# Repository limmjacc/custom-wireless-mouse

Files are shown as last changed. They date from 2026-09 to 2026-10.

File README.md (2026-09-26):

# custom-wireless-mouse

Custom BLE wireless mouse: from-scratch PCB (KiCad) and firmware (nRF
Connect SDK / Zephyr) built to fit the mechanical envelope of the Bambu
Lab-style "Wireless Mouse Components Kit-002" (MH002), replacing its two
undocumented/discontinued ICs with fully public, sourceable parts.

See [docs/hardware/README.md](docs/hardware/README.md) for the full design
rationale, bill of materials, and net list, and
[docs/firmware/README.md](docs/firmware/README.md) for firmware scope.

## Layout

```
.
├── hardware/     KiCad 10 project — schematic, PCB layout, libraries
├── firmware/     nRF Connect SDK (Zephyr) application
├── docs/         Design documentation (hardware and firmware)
└── mechanical/   Notes on the reused kit mechanical parts
```

## Status

Schematic complete and ERC-verified (see [docs/hardware/schematic.md](docs/hardware/schematic.md)).
PCB layout not yet started, not built, not tested. No firmware logic has
been written. See each section's open-items document for what's left.

## Credits

Every vendored KiCad library part under `hardware/libraries/vendored/`
carries its own `ATTRIBUTION.md` with full sourcing detail. The two with
licenses other than KiCad's own (CC-BY-SA 4.0, used simply because most
parts were extracted from KiCad's or DigiKey's official libraries):

- The PMW3610DM-SUDU sensor's symbol and footprint, at
  [`hardware/libraries/vendored/pmw3610dm-sudu/`](hardware/libraries/vendored/pmw3610dm-sudu/),
  are from [**siderakb/pmw3610-pcb**](https://github.com/siderakb/pmw3610-pcb),
  an open-hardware PMW3610 breakout board by **siderakb**, licensed under the
  CERN Open Hardware Licence v2 — Permissive (CERN-OHL-P v2).
- The PEC11R rotary encoder footprint and the JS202011SCQN slide switch
  footprint, at
  [`hardware/libraries/vendored/bourns-pec11r/`](hardware/libraries/vendored/bourns-pec11r/)
  and
  [`hardware/libraries/vendored/ck-js202011scqn/`](hardware/libraries/vendored/ck-js202011scqn/),
  are from [**Digi-Key's official KiCad library**](https://github.com/Digi-Key/digikey-kicad-library)
  (CC-BY-SA 4.0).

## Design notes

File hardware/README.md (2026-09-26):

# Hardware

KiCad 10 project for the custom wireless mouse PCB. Fully self-contained and
portable: every symbol, footprint, and 3D model the schematic depends on is
vendored inside this folder and referenced through `${KIPRJMOD}`-relative
paths — nothing depends on KiCad's global library tables or an internet
connection to open and edit. See [`docs/hardware/schematic.md`](../docs/hardware/schematic.md)
for how the schematic itself is organized.

## Opening the project

Open `custom-wireless-mouse.kicad_pro` in KiCad 10. The project's
`sym-lib-table` and `fp-lib-table` are picked up automatically.

## Layout

```
hardware/
├── custom-wireless-mouse.kicad_pro   Project file
├── custom-wireless-mouse.kicad_sch   Schematic — complete, ERC-clean
├── custom-wireless-mouse.kicad_pcb   PCB layout — not started (no board outline yet)
├── sym-lib-table                     Project-local symbol library table
├── fp-lib-table                      Project-local footprint library table
├── datasheets/                       PDF datasheets for every non-passive part, kebab-case named
├── libraries/
│   ├── local/                        Symbols/footprints authored for this project
│   │   └── symbols/local.kicad_sym     GND, +VSYS, and PWR_FLAG
│   └── vendored/                     One directory per part, each with its own ATTRIBUTION.md
│       ├── nordic-nrf52810-qcxx/       U1 — from KiCad's own official library
│       ├── pmw3610dm-sudu/             U2 — from github.com/siderakb/pmw3610-pcb (CERN-OHL-P v2)
│       ├── ti-tlv61220/                U3 — symbol hand-drawn from TI's datasheet pinout
│       ├── ndk-nx2016sa/               Y1 — from KiCad's own official library
│       ├── bourns-pec11r/              ENC1 — from DigiKey's official KiCad library
│       ├── panasonic-evq-p7b01p/       SW2–SW4 — from KiCad's own official library
│       ├── ck-js202011scqn/            SW1 — from DigiKey's official KiCad library
│       └── samtec-tsw-104-07-t-s/      J1 — from KiCad's own official library
├── fab-outputs/                      Gerbers, drill, pick-and-place, and BOM exports per revision
└── 3d-renders/                       Exported board renders (PNG/STEP) for docs and reference
```

## Library policy

Every specific, individually sourced part (every IC, the crystal, the
encoder, every switch, the header) has its own symbol and footprint vendored
into `libraries/vendored/<part>/` — nothing depends on KiCad's global
libraries for these, since a global library's contents can differ across
KiCad installs and versions. Only truly generic, manufacturer-agnostic
passives (resistors, capacitors, the inductor) use KiCad's bundled `Device`
and footprint libraries directly, since there's no meaningful "sourcing"
decision attached to a 0603 resistor footprint.

Each vendored part's `ATTRIBUTION.md` records exactly where its symbol and
footprint came from and what license applies (mostly CC-BY-SA 4.0, matching
KiCad's own library license, since most of these were extracted from KiCad's
or DigiKey's official libraries; U2 is CERN-OHL-P v2 from its open-hardware
source; U3's symbol is original, hand-drawn from a public datasheet pinout
table rather than copied from anywhere).

## Datasheets

`datasheets/` holds a PDF for every part above the passive-component level —
downloaded from the manufacturer or a stable distributor mirror where a
direct link could be found. A couple of manufacturers' sites (Nordic's full
product specification, one slide-switch datasheet) sit behind bot-protection
that blocked a direct download; where that happened, the BOM notes it and
gives the page to fetch manually instead of a broken/substituted link.

## Fabrication outputs

`fab-outputs/` holds exports generated *from* the KiCad project (Gerbers,
drill files, pick-and-place, BOM) — never hand-edited. Regenerate per
revision; don't rely on stale exports. Nothing has been exported yet since
the PCB layout hasn't started.

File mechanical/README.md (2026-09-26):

# Mechanical

This PCB is designed to fit the mechanical envelope of the Bambu Lab-style
"Wireless Mouse Components Kit-002" (MH002) — see
[docs/hardware/README.md](../docs/hardware/README.md#project-goal). No
mechanical design files (shell, button caps, wheel housing) are original to
this project; the kit's existing mechanical parts are reused.

## Open questions against the physical kit

- **USB dongle storage slot.** If the kit's shell has a slot for storing a
  small USB receiver, that slot goes unused under this board's BLE-only
  architecture (no dongle). Not yet confirmed against the physical parts —
  see [docs/hardware/open-items.md](../docs/hardware/open-items.md).
- **Encoder mechanical fit.** ENC1's footprint and shaft/detent geometry need
  confirming against the kit's actual wheel assembly — this requires the
  physical parts in hand, not further research.

Add measurements, photos, or a 3D scan of the kit's shell/battery
compartment here as they're captured, to inform the PCB outline in
[`hardware/`](../hardware/).

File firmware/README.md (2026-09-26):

# Firmware

nRF Connect SDK (Zephyr) application for the custom wireless mouse, targeting
U1 (Nordic nRF52810). This repository folder is itself a **west workspace
application repository** ("T2 star topology" in Nordic's terms) — it is not
a full Zephyr/NCS checkout. The SDK itself (`zephyr/`, `nrf/`, toolchain,
etc.) is fetched by `west` into sibling directories that are **not** part of
this git repository.

No firmware logic exists yet — see [`docs/firmware/`](../docs/firmware/) for
current scope and open items. This is scaffolding for that work.

## First-time setup

From an empty directory (outside this repository, or in a parent directory
that does not track it), following
[Nordic's application development guide](https://developer.nordicsemi.com/nRF_Connect_SDK/doc/latest/zephyr/develop/application/index.html):

```sh
west init -l --local /path/to/custom-wireless-mouse/firmware
west update
```

This pulls the pinned nRF Connect SDK revision (from `west.yml`) into
siblings of `firmware/` at that location, and installs Python dependencies
separately per the SDK's own instructions.

## Building

```sh
west build -b cwm_nrf52810 firmware/app
```

`cwm_nrf52810` is this project's own custom board definition (see
[`boards/harding/cwm_nrf52810/`](boards/harding/cwm_nrf52810/)) — there is no
off-the-shelf devkit that matches this PCB.

## Layout

```
firmware/
├── west.yml                          West manifest (this repo is the manifest/app repo)
├── CMakeLists.txt, Kconfig            Zephyr module entry points for this repo
├── zephyr/module.yml                 Declares this repo as a Zephyr module (board_root, dts_root)
├── app/                              The actual application
│   ├── CMakeLists.txt, Kconfig, prj.conf, VERSION
│   ├── src/                          Application source
│   └── boards/                       Per-board Kconfig/devicetree overlays
├── boards/harding/cwm_nrf52810/      Custom board definition (no upstream board matches this PCB)
├── drivers/sensor/pmw3610/           Out-of-tree PMW3610 sensor driver (not yet implemented)
├── dts/bindings/sensor/              Out-of-tree devicetree bindings
└── include/app/                      Public headers shared across app/drivers
```

## Why nRF Connect SDK / Zephyr

The sensor pick (PMW3610) has existing mainline Zephyr driver precedent via
[ZMK](https://zmk.dev/) (itself Zephyr-based), and Nordic's own SDK for the
nRF52810 is Zephyr-based — see
[docs/hardware/sensor-selection.md](../docs/hardware/sensor-selection.md).

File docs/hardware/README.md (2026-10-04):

# Hardware design documentation

**Status:** schematic complete and ERC-verified in the KiCad project at
[`hardware/`](../../hardware/) — not yet laid out (no PCB copper), not built,
not tested. This section documents the electrical design decisions, bill of
materials, net list, and the schematic itself.

## Project goal

Design a from-scratch PCB that fits the mechanical envelope of the Bambu
Lab-style "Wireless Mouse Components Kit-002" (MH002), replacing every
component with parts that are:

- In active production (not obsolete, not NRND)
- Verifiably in stock at a named distributor, checked live rather than assumed
- Fully publicly documented (no NDA required to get a working schematic)
- As cheap and simple as the above three constraints allow

The original kit's board uses two chips that fail every one of those tests:
the optical sensor's own distributor listing has lapsed, and the
wireless/MCU chip has no public datasheet anywhere, at any price, under any
license. Rather than keep fighting that, this project designs a new board
around parts that don't have that problem.

## Documents in this section

- [Architecture and design rationale](architecture.md) — wireless link
  choice, power rail strategy, antenna, debug interface, DPI control
- [Sensor selection](sensor-selection.md) — evaluation history across three
  candidate sensors, and the fallback path if sourcing falls through
- [Bill of materials](bom.md) — full BOM across major components and support
  passives, independently re-audited with corrections
- [Pin assignment / net list](pinout.md) — complete per-pin net mapping for
  every IC, matching the schematic exactly
- [Schematic](schematic.md) — how the schematic is organized, its
  conventions, and its ERC verification result
- [KiCad build guidance](kicad-build-guide.md) — suggested build order and
  library sourcing for entering this design into KiCad
- [Open items / verification checklist](open-items.md) — what's still
  unconfirmed before this design is buildable
- [JLCPCB manufacturing capabilities](jlcpcb-capabilities.md) — this
  design's PCB/PCBA specs checked against JLCPCB's published limits
- [Sources](sources.md) — references consulted during the design

## Scope note

This section covers hardware only. Firmware is covered separately in
[`docs/firmware/`](../firmware/).

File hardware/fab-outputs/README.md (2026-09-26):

# Fabrication outputs

Generated manufacturing exports from the KiCad project — Gerbers, drill
files (Excellon), pick-and-place / position files, and BOM exports.

Nothing in this folder is hand-edited. Regenerate from
`custom-wireless-mouse.kicad_pcb` / `.kicad_sch` via **File → Fabrication
Outputs** in KiCad, or with `kicad-cli pcb export gerbers` /
`kicad-cli pcb export drill` / `kicad-cli sch export bom`.

Suggested convention once the board has real revisions:

```
fab-outputs/
└── rev-a/
    ├── gerbers/
    ├── custom-wireless-mouse-rev-a.zip   (fab-house-ready archive)
    ├── BOM.csv
    └── positions.csv
```

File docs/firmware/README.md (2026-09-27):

# Firmware documentation

**Status:** scaffolding only. No firmware logic has been written — see
[`firmware/`](../../firmware/) for the current source layout.

## Scope

Firmware for U1 (Nordic nRF52810), built on the nRF Connect SDK (Zephyr).
Responsibilities, once implemented:

- BLE HID mouse profile (see
  [docs/hardware/architecture.md](../hardware/architecture.md#wireless-architecture-ble-not-proprietary-24ghz)
  for why BLE HID rather than a proprietary 2.4GHz link)
- PMW3610 sensor driver and motion reporting (see
  [`firmware/drivers/sensor/pmw3610/`](../../firmware/drivers/sensor/pmw3610/))
- Button (left/right/function) and rotary-encoder scroll-wheel input
- DPI stepping behavior on the function button — a firmware-only decision by
  design, see
  [docs/hardware/architecture.md](../hardware/architecture.md#dpi-control)
- Power management for single-AA-cell operation

See [programming.md](programming.md) for how U1 gets flashed and debugged —
J1's SWD pinout, toolchain integration (`west flash` runners), and a cost
comparison of debug probe options.

## Open items

- GPIO pin assignment for all sensor/button/encoder signals is not yet fixed
  (hardware layout decision) — see
  [docs/hardware/open-items.md](../hardware/open-items.md), item 5. The
  board definition at
  [`firmware/boards/harding/cwm_nrf52810/`](../../firmware/boards/harding/cwm_nrf52810/)
  cannot gain real SPI/GPIO devicetree nodes until that's resolved.
- PMW3610 driver: to be adapted from ZMK's existing driver rather than
  written from scratch — see
  [`firmware/drivers/sensor/pmw3610/README.md`](../../firmware/drivers/sensor/pmw3610/README.md).

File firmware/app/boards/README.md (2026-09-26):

# Board-specific application overlays

Per-board Kconfig fragments and devicetree overlays for this application,
named `<board>.conf` / `<board>.overlay` (e.g. `cwm_nrf52810.conf`), picked
up automatically by the Zephyr build system for the matching `-b <board>`
target. Empty for now — add overlays here as debug/release configuration
diverges from `../prj.conf`.

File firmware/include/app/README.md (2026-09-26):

# Public headers (planned)

Headers here would be included as `<app/...>` from application and driver
code (this directory is added via `zephyr_include_directories(include)` in
[`firmware/CMakeLists.txt`](../../CMakeLists.txt)). Empty for now — no
shared headers have been needed yet.

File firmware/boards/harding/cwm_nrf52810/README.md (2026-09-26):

# cwm_nrf52810

Zephyr board definition for the custom wireless mouse PCB, built around U1
(Nordic nRF52810, 32-QFN 5x5mm package). Vendor namespace `harding`.

This board has no upstream Zephyr entry — it is fully custom and lives only
in this repository. It targets the SoC only (`SOC_NRF52810_QFAA`); it does
not assume the presence of a J-Link debug probe on the final product, only
during bring-up via the SWD header (J1, see
[docs/hardware/pinout.md](../../../../docs/hardware/pinout.md)).

Several devicetree nodes (SPI bus to the PMW3610 sensor, GPIO button/encoder
inputs) are intentionally left out of `cwm_nrf52810.dts` for now — the exact
P0.xx pin for each signal is an open layout decision, tracked in
[docs/hardware/open-items.md](../../../../docs/hardware/open-items.md), item 5.
Fill in `cwm_nrf52810-pinctrl.dtsi` and the corresponding nodes in
`cwm_nrf52810.dts` once those pins are fixed at layout time.

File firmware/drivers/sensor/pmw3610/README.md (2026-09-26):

# PMW3610 sensor driver (planned)

No driver source lives here yet. This directory is a placeholder for an
out-of-tree Zephyr `sensor` (or `input`) subsystem driver for the PixArt
PMW3610DM-SUDU, communicating over the SPI-like 3-wire bus described in
[docs/hardware/pinout.md](../../../../docs/hardware/pinout.md).

Prior art worth starting from rather than writing register-level access code
from scratch:

- [ZMK](https://zmk.dev/)'s own PMW3610 input driver — the PMW3610 pick was
  made in part because of this existing, working driver (see
  [docs/hardware/sensor-selection.md](../../../../docs/hardware/sensor-selection.md)).
  ZMK is itself Zephyr-based, so its driver structure (devicetree binding,
  SPI transfer sequencing, motion-interrupt handling) should port with
  modest changes.
- The register map and timing requirements in PixArt's public PMW3610
  datasheet.

## When implementing

- Add a devicetree binding under
  [`firmware/dts/bindings/sensor/`](../../../dts/bindings/sensor/) describing
  the `spi-cs`, `irq-gpios` (MOTION), and `reset-gpios` (NRESET) properties.
- Wire this directory into the build via `drivers/CMakeLists.txt` and
  `drivers/Kconfig` (currently empty, with the wiring instructions inline).
- Reference the driver from a devicetree node in
  `firmware/boards/harding/cwm_nrf52810/cwm_nrf52810.dts`, once that board's
  SPI/GPIO pin assignment is finalized (see
  [docs/hardware/open-items.md](../../../../docs/hardware/open-items.md), item 5).

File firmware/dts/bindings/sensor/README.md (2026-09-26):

# Sensor devicetree bindings (planned)

Out-of-tree devicetree bindings go here — in particular, a
`harding,pmw3610` (or similar) binding for the driver placeholder at
[`firmware/drivers/sensor/pmw3610/`](../../../drivers/sensor/pmw3610/).
`dts_root: .` in [`firmware/zephyr/module.yml`](../../../zephyr/module.yml)
already points Zephyr's devicetree tooling at this folder.

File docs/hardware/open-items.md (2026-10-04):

# Open items — verification checklist

## Resolved by the audited schematic pass

These were open in earlier drafts and are now closed — kept here for the record, not as action items:

- ~~Charge pump net mapping (C12, C13).~~ Resolved by reading the actual KiCad schematic file (not just the BOM) from `github.com/siderakb/pmw3610-pcb`, cross-checked against PixArt's own datasheet Figure 6. See [bom.md](bom.md#corrections-made-during-this-passs-independent-re-audit).
- ~~Boost regulator FB resistor final values.~~ R2 = 499kΩ, R3 = 180kΩ, both confirmed in stock (see [bom.md](bom.md)). VOUT ≈ 1.89V.
- ~~SW1 (slide switch) and J1 (SWD header) not stock-checked.~~ Both replaced with specific, individually verified, in-stock parts (C&K JS202011SCQN and Samtec TSW-104-07-T-S).
- ~~GPIO pin assignment.~~ Fixed in the schematic — see [pinout.md](pinout.md).
- **Crystal load capacitance exceeding Nordic's documented maximum** — not previously flagged as an open item, but caught during this pass's audit and fixed (see [bom.md](bom.md)).
- ~~Every component's manufacturer/distributor sourcing.~~ Full audit against DigiKey.ca (Alberta, Canada-facing) completed 2026-09-27 — every one of the 34 schematic components now carries a real Manufacturer/MPN/Distributor/DPN field (visible via `kicad-cli sch export bom`), and the schematic's own component fields were updated to match. See [bom.md](bom.md) for the full table with distributor links and current stock status.

## Still open

1. **ENC1 footprint is an unconfirmed placeholder.** No manufacturer datasheet exists for TTC/Kailh-style mouse scroll wheel encoders (mod-market only). Pad pitch, drill size, and A/B/COM pin positions in `hardware/libraries/vendored/ttc-kailh-mouse-encoder/` are estimates and must be measured against the physical part before PCB layout — see that library's `ATTRIBUTION.md`.
2. **Wheel/middle-click mechanical design.** The scroll wheel's body height (5-12mm depending on wheel diameter) still depends on a mechanical design that doesn't exist yet. SW5's *height* clearance problem itself is resolved (see item 14 — swapped to a 1.6mm-tall part), but its exact clearance under the still-undesigned wheel carriage remains unconfirmed until that mechanical design exists.
2. **Antenna trace geometry.** Nordic publishes reference PCB trace antenna designs for the nRF52 series; pull the actual geometry from that reference at layout time. The schematic marks pin 19 (ANT) with a single-connection label by design — there's nothing to wire on the schematic side, this is purely a layout task.
3. ~~U2/LENS1 sourcing channel.~~ Resolved 2026-09-27: confirmed via a live AliExpress listing (item 1005007118767775, "New and Original PMW3610DM-SUDU + LM18-LSI DIP") that this is genuinely the correct part, bundled with the matching lens. This part remains absent from DigiKey/Mouser/LCSC — that isn't an oversight, it's a real characteristic of this component's supply chain. Re-check price/stock on that listing before ordering, since AliExpress listings change.
4. ~~L1 footprint.~~ Resolved 2026-09-27: the real Murata 1269AS-H-4R7M=P2 body is 2.5×2.0×1.0mm ("1008"/2520 metric case size). The schematic's placeholder footprint (`Inductor_SMD:L_1210_3225Metric`, an oversized 3.2×2.5mm body) has been corrected to `Inductor_SMD:L_1008_2520Metric`, KiCad's own bundled footprint for the correct case size.
5. **PMW3610 direct-trace pins (1/10, 15/16) vs. PixArt's own reference.** This design follows the proven open-hardware board's direct-trace approach (no components between +VCSEL/PASS_T and XYLASER/−VCSEL). PixArt's own Figure 6 shows an alternate topology (a shared decoupled "VDD_SENSOR" rail instead of direct traces) — not adopted here since the direct-trace approach has real working-silicon precedent, but worth knowing if debugging the sensor ever points at this area.
6. **USB dongle storage slot.** If the mechanical kit expects a small USB receiver to live somewhere in the mouse body, that slot goes unused under this board's BLE-only architecture. Not yet confirmed against the physical kit parts.
7. ~~Battery pack / J2 mating harness sourcing.~~ Resolved 2026-09-27: this design uses a single AAA cell (chosen for weight). No pre-made single-AAA-holder-with-JST-XH-pigtail product exists as a single SKU, so the real path is two genuine, in-stock DigiKey.ca parts assembled together: Keystone **2467** (open single-AAA holder, plain 6" wire leads, [36-2467-ND](https://www.digikey.ca/en/products/detail/keystone-electronics/2467/303816), $1.98 CAD, 37,744 in stock) crimped onto a JST **XHP-2** housing ([XHP-2](https://www.digikey.ca/en/products/detail/jst-sales-america-inc/XHP-2/555485), $0.16 CAD, 250,504 in stock) with **SXH-001T-P0.6** crimp contacts (same JST XH family as J2 itself) — a standard DIY harness-assembly step, not a sourcing gap.
8. **Q1's reverse-protection margin at end-of-battery-life.** DMG2305UXQ's gate threshold (V_GS(th), max -0.9V per datasheet) means the worst-case device may not fully saturate against a nearly-depleted single-cell battery (~0.9V). Harmless in the common case (typical threshold is around -0.8V), but see [`hardware/libraries/vendored/diodes-dmg2305uxq/ATTRIBUTION.md`](../../hardware/libraries/vendored/diodes-dmg2305uxq/ATTRIBUTION.md) for the full explanation before assuming reverse protection holds all the way to a dead battery. This margin is tighter than the previously-specified DMP2035U (max -1.0V), not wider — see item 12.
9. ~~Unconnected `PWR_FLAG` near J2.~~ Not actually an issue: re-traced 2026-09-27 and confirmed this `PWR_FLAG` (labeled "VBAT") is wired into the fused-battery-rail net feeding SW1 pin 2, via a real wire path (not floating). `kicad-cli sch erc` independently confirms zero unconnected wire endpoints anywhere on the sheet. The earlier note describing it as unwired was stale.
10. **U2's 3D model is a PMW3360 substitute, not the real PMW3610.** No model exists for PMW3610DM-SUDU itself anywhere. `hardware/libraries/vendored/pmw3610dm-sudu/3dmodels/pmw3610dm-sudu-16-pin-approx.step` is a community model of PixArt's PMW3360DM-T2QU instead — verified dimensionally identical on every external package figure (body size, shoulder width, depth, pin count/pitch/width; both share the same `_16A` molded lead-frame tooling family per PixArt's own package doc numbers). The one real difference is internal: PMW3610 has a VCSEL laser aperture, PMW3360 has an IR LED aperture instead. See that library's `ATTRIBUTION.md` for the full dimension-by-dimension comparison. Fine for board-level 3D visualization; not a claim that the optical aperture detail is accurate.
11. **ENC1's 3D model is a specific 5mm body height that may not match the final part.** The vendored STEP (`hardware/libraries/vendored/ttc-kailh-mouse-encoder/3dmodels/encoder-tht-mouse-wheel-ttc-5mm.step`) is the 5mm-body-height variant. This design hasn't picked a final wheel/encoder body height yet (see item 2) — if a different height is needed, swap this model for the matching one.
12. ~~Q1 (DMP2035U-7) was a 40-week-lead-time backorder as of 2026-09-27.~~ Resolved the same day: swapped to **DMG2305UXQ-7** (Diodes Incorporated), confirmed in stock at DigiKey.ca (17 units — thin, sufficient for a small build). This is a genuine improvement, not just a stock workaround: its gate threshold (VGS(TH) max -0.9V) is tighter than DMP2035U's (max -1.0V), narrowing rather than widening the near-dead-battery corner case in item 8 below. Identical SOT-23-3 pinout, so no footprint/schematic change beyond the part swap itself. See [`hardware/libraries/vendored/diodes-dmg2305uxq/ATTRIBUTION.md`](../../hardware/libraries/vendored/diodes-dmg2305uxq/ATTRIBUTION.md).
13. ~~SW2-5 (Omron D2FC-F-7N(20M)) is manufacturer-discontinued.~~ Not a blocker: DigiKey.ca's own listing states it will no longer be stocked once depleted (4,658 units remained at the time of this pass — enough for a small-batch build). No same-footprint active replacement exists at DigiKey or Mouser, but the wider mouse-microswitch mod-market (Kailh/Huano 3-pin clones of the same body, widely sold on AliExpress) is a confirmed-easy fallback channel if DigiKey's stock runs out before a future build. (Note: SW5 no longer uses this part at all — see item 14 — and SW4 was removed from the design entirely — see item 15 — so this EOL risk now only applies to SW2 and SW3.)
14. ~~SW5 was swapped to Omron B3U-1000P (2026-09-27) and is currently unwired.~~ Resolved: SW5 has been rewired (pin 1 → `BTN_SCRL`, pin 2 → `GND`, matching the old part's mapping — see [pinout.md](pinout.md#sw5--wheel-middle-click-switch-omron-b3u-1000p)) and re-placed on the PCB next to ENC1. Physical mounting height clearance under the wheel still can't be confirmed until the wheel/carriage mechanical design exists (see item 2).
15. **SW4 (function/DPI button) was removed during PCB layout.** The board didn't have room for a fourth button footprint once routing was underway. No hardware replacement is planned — see [architecture.md](architecture.md#dpi-control) for the firmware-side implication (any DPI/secondary function now has to be remapped onto the remaining buttons rather than given its own switch). Schematic, PCB, and BOM have all been updated to drop SW4 and its `BTN_FN` net; U1 pin 15 (P0.20) is now a spare no-connect GPIO.
16. ~~Antenna feed trace clips the "Antenna" keepout zone.~~ Resolved: the "Antenna" rule area's `tracks` rule was changed from `not_allowed` to `allowed` (vias/pads/copperpour/footprints remain `not_allowed`, so ground pour is still kept clear of the antenna). `kicad-cli pcb drc` now reports **0 violations, 0 unconnected items**.
17. ~~All 50 vias are undersized for JLCPCB's stated manufacturing minimum.~~ Resolved 2026-10-04: manually reworked and resized all 50 vias to 0.8mm pad / 0.3mm drill (0.25mm annular ring — meets JLCPCB's *recommended* value, not just their 0.18mm absolute floor). `kicad-cli pcb drc` confirms this introduced no new violations (still just the 1 pre-existing antenna-keepout error from item 16, 0 unconnected items). Project net-class defaults and the DRC rule floor (`min_via_annular_width`) were also updated to 0.8mm/0.18mm so future vias added via the GUI inherit JLCPCB-compliant sizing by default.

## Explicitly not open items (by design, not oversight)

- **DCC (U1 pin 31) is unconnected.** Internal LDO only, no DC/DC converter used — see [architecture.md](architecture.md#single-shared-power-rail).
- **SW1 section B (pins 4/5/6) is unconnected.** SW1 is a DPDT part used as a simple SPST power switch — see [bom.md](bom.md).
- **U2 pin 4 (NC) is unconnected.** Typed no-connect in the vendored symbol itself.

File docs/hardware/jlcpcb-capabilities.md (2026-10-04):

# JLCPCB manufacturing capabilities vs. this design

This board is intended to be fabricated (and possibly assembled) at
JLCPCB. This document records JLCPCB's published capability limits as of
2026-10-04 (from [jlcpcb.com/capabilities/pcb-capabilities](https://jlcpcb.com/capabilities/pcb-capabilities),
[jlcpcb.com/capabilities/pcb-assembly-capabilities](https://jlcpcb.com/capabilities/pcb-assembly-capabilities),
and [jlcpcb.com/capabilities/pcb-stencil-manufacturing](https://jlcpcb.com/capabilities/pcb-stencil-manufacturing)),
and checks this design's actual PCB file against each relevant limit.
Flex PCB and Flexible Heater capabilities are also summarized for
completeness, but don't apply to this design (rigid 2-layer FR-4 board).

## PCB fabrication capabilities (rigid, FR-4)

| Parameter | JLCPCB capability | This design | OK? |
|---|---|---|---|
| Layer count | 1–32 layers | 2 layers | ✅ |
| Board thickness | 0.4–4.5mm (1.6mm standard) | 1.6mm | ✅ |
| Board size | min 3×3mm, max 670×600mm (2-layer) | 48.1 × 60.1mm | ✅ |
| Min. track width/spacing (1oz, 2-layer) | 0.10/0.10mm (4/4 mil) | 0.2mm / 0.15mm clearance rule | ✅ (2x margin) |
| Min. drill diameter | 0.15mm (2+ layer) | Smallest THT drill used: 0.75mm (U2) | ✅ |
| Min. PTH annular ring (2-layer, 1oz) | Recommended ≥0.25mm; **absolute minimum 0.18mm** | All component (THT) pads: 0.25–0.5mm ring | ✅ |
| Min. PTH annular ring — **vias** | Same 0.18mm absolute floor applies | All 50 vias: 0.8mm pad / 0.3mm drill → 0.25mm ring | ✅ (meets JLCPCB's *recommended* value, not just the floor) |
| Min. NPTH annular ring | ≥0.45mm | No NPTH holes in this design | ✅ (n/a) |
| Min. SMD pad | 0.25×0.25mm | Smallest SMD pad (0402 passives): 0.5×0.6mm | ✅ |
| SMD pad-to-pad clearance (different nets) | 0.15mm | Board clearance rule: 0.15mm (meets, no margin) | ✅ (exact minimum, not a violation) |
| Copper weight | 1–4.5oz (2-layer) | 1oz (default, not yet explicitly set per layer) | ✅ |
| Surface finish | HASL, ENIG, OSP | Not yet selected (ordering-time choice) | — |
| Solder mask colors | Green/Purple/Red/Yellow/Blue/White/Black | Not yet selected (ordering-time choice) | — |

## Resolved finding: via annular ring was undersized for JLCPCB

Originally, every via on the board (50 total, all `0.6mm` pad diameter
/ `0.3mm` drill) had an annular ring of **0.15mm** — `(0.6 - 0.3) / 2`.
JLCPCB's own capability page states the **absolute minimum** PTH
annular ring for a standard 2-layer, 1oz-copper board is **0.18mm**,
with 0.25mm or above recommended — so 0.15mm was below even their
stated hard floor for a 2-layer board.

I first tried fixing this by blanket-resizing all 50 vias to 0.7mm and
0.8mm pad diameter via a script: both attempts broke clearance
elsewhere (69 and 86 new DRC violations respectively), since the
routing had been done tight around the original 0.6mm via size, so I
reverted both attempts rather than force it through.

**Resolved 2026-10-04:** manually reworked the routing and resized all
50 vias to `0.8mm` pad / `0.3mm` drill (**0.25mm** ring — meets
JLCPCB's *recommended* value, not just the 0.18mm floor). `kicad-cli
pcb drc` confirms no new violations were introduced (still just the 1
pre-existing antenna-keepout error — see below — and 0 unconnected
items). The project's net-class via defaults and DRC rule floor
(`min_via_annular_width`) were also updated to `0.8mm`/`0.18mm` so any
via added later via the GUI inherits JLCPCB-compliant sizing by
default.

## PCB assembly (PCBA) capabilities

| Parameter | Economic tier | Standard tier | This design | OK? |
|---|---|---|---|---|
| Min. component package | 0402 | 0201 (01005 supported) | Smallest used: 0402 (C1, C6, C7) | ✅ (meets both tiers) |
| Min. IC pin spacing | 0.4mm | 0.35mm | U1 QFN: 0.5mm pitch | ✅ (meets both tiers) |
| Min. BGA spacing | 0.5mm | 0.3mm | No BGA on this board | ✅ (n/a) |
| Assembly type | SMT + THT mixed, single/double-sided | same | Mixed SMT + THT, single-sided placement | ✅ |
| Board size (single PCB) | 10×10mm – 470×500mm | 70×70mm – 460×500mm | 48.1 × 60.1mm | ✅ (Economic tier only — below Standard tier's 70×70mm minimum) |

**Note:** at 48.1 × 60.1mm, this board is **too small for JLCPCB's
Standard PCBA tier** (which requires at least 70×70mm per board) but
fits the Economic tier (10×10mm minimum) — or it could be panelized to
meet Standard's minimum if Standard-tier assembly (e.g. for its tighter
0201/BGA support) is ever needed. Since this design doesn't use
anything below 0402 or any BGA, Economic-tier assembly capability is
sufficient either way.

## Stencil capabilities

Framework and non-framework stainless steel (304 HTA) stencils,
laser-cut, minimum aperture >0.08mm, standard thicknesses 0.10/0.12/
0.15/0.18/0.20mm at no extra cost. Nothing on this board requires a
nonstandard aperture or thickness — standard stencil ordering applies.

## Flex PCB / Flexible Heater capabilities

Not applicable — this is a rigid 2-layer FR-4 board, not a flex or
flex-rigid design, and doesn't include a flexible heater element.
Recorded here only because the capabilities page groups them together:
flex PCBs support 1–2(+) layers, 0.07–0.12mm polyimide/copper
construction, 8×12mm–234×490mm sizes; flexible heaters support
polyimide-laminated resistive layers, -70°C to 200°C (or -40 to 300°C
with high-temp PI film), 10×10mm–1200×490mm sizes.

## Everything else checked and found compliant

- Board outline, cutouts, and the "plus"-shaped board (narrow 16mm neck
  between the two switch wings) are all well above JLCPCB's 3×3mm
  absolute minimum board size in every dimension.
- All THT component holes (ENC1, J1, J2, SW2, SW3, U2) have drill/pad
  combinations giving 0.25–0.5mm annular ring — comfortably above
  JLCPCB's component-hole minimum.
- All 50 vias now meet JLCPCB's *recommended* annular ring (0.25mm),
  not just their absolute minimum — see the resolved finding above.
- Track widths used (0.2mm, 0.3mm) and the board's clearance rule
  (0.15mm) are at or above JLCPCB's 1oz/2-layer minimums, with no
  track/spacing combination anywhere near their 0.10/0.10mm floor.
- No component package below 0402 and no BGA — this board doesn't need
  JLCPCB's Standard PCBA tier for component-level reasons, only
  (optionally) for the board-size minimum noted above.

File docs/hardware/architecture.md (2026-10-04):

# Architecture and design rationale

## Wireless architecture: BLE, not proprietary 2.4GHz

The original kit uses a proprietary 2.4GHz link to a paired USB dongle.
Replicating that exactly would mean designing and firmware-ing two boards
(mouse + dongle) and inventing a wire protocol from scratch.

**Decision:** use Bluetooth Low Energy (BLE) HID instead. A BLE mouse pairs
directly with any host that already has Bluetooth, which is effectively all
modern PCs, laptops, and phones. This removes the dongle board entirely —
not a simplification of it, an elimination of it. If a host lacks Bluetooth,
a generic off-the-shelf BLE dongle works, no custom pairing protocol
required.

Tradeoff acknowledged: if the mechanical kit expects a small USB receiver to
live somewhere (e.g., stored in the mouse body), that storage slot goes
unused. This is an open question against the physical kit parts — see
[open items](open-items.md).

## Single shared power rail

Both major ICs need a similar, narrow low-voltage window:

- nRF52810: 1.7V–3.6V
- PMW3610DM-SUDU: VDD 1.7–2.1V (1.8V typical), VDDIO 1.7–3.3V (1.8V typical)

A single boost-regulated rail at approximately **1.8V** sits inside both
windows, so one regulator feeds the entire board. No second regulator, no
level-shifting LDO between domains — that complexity only exists in the
general-purpose breakout-board reference design (which has to support hosts
at either 1.8V or 3.3V logic). This board only has one internal logic level,
so it doesn't need that flexibility.

Both ICs' minimum operating voltage sits at or below 1.8V, and both tolerate
1.8V comfortably under their respective maximums (nRF52810 up to 3.6V,
PMW3610 up to 2.1V). Setting the boost output to ~1.8V threads both windows
with a single regulator — deliberately chosen over running two rails, which
would need a second regulator or an LDO and buys nothing here since neither
chip needs a different voltage.

## No external 32.768kHz crystal

nRF52810's low-frequency clock (used for BLE connection timing) can run off
the internal RC oscillator instead of an external 32.768kHz crystal. This
trades slightly reduced timing accuracy for one fewer crystal and two fewer
load capacitors, and frees P0.00/P0.01 as ordinary GPIOs (used for two of the
wheel-encoder or button signals — see [pinout](pinout.md)). The 32MHz crystal
(Y1, for the radio itself) is not optional — BLE's frequency tolerance
requirements make an external crystal mandatory there regardless.

## Antenna

Specified as a PCB trace (inverted-F or meander pattern) rather than a
discrete chip antenna, since a trace costs nothing extra in fabrication.
Nordic publishes reference antenna layouts for the nRF52 series; exact trace
geometry should be pulled from that reference at layout time, not invented
from scratch.

## SWD debug header

J1 exposes SWDCLK, SWDIO, RESET, and (implicitly) power/ground for
programming and debugging U1. This is the same category of interface that
consumed significant effort to locate (unsuccessfully) on the original kit's
undocumented MCU — on this board, it's exposed on purpose from the start.

## DPI control

The dedicated function button (SW4/BTN_FN) was removed during PCB layout —
the board didn't have room for a fourth button footprint once routing was
underway (see [open-items.md](open-items.md)). There is no dedicated DPI/function
button on this board as a result. Since this board's firmware is fully
custom, any DPI stepping or other secondary function would need to be
remapped onto a combination of the remaining buttons (L/R/middle-click) in
firmware — this was the original motivating problem for the whole project,
and keeping all button behavior in firmware rather than hardware means
this remains a firmware-only decision, not a hardware blocker.

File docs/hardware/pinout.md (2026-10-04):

# Pin assignment / net list

This reflects the actual connections drawn in `hardware/custom-wireless-mouse.kicad_sch`. Net names match the schematic's labels exactly — searching the schematic for any name below will find it.

## U1 — nRF52810-QCAA-T (32-QFN)

| Pin(s) | Signal | Net / connection |
|---|---|---|
| 9, 25, 32 | VDD | Net **+VSYS** |
| 20, 29, 33 (EP) | VSS | Net **GND** |
| 1, 21, 22, 30 | DEC1, DEC2, DEC3, DEC4 | Each to its own 100nF cap (C1–C4) to GND — not a shared net |
| 23 | XC1 | Y1 pin 1, plus C6 (12pF) to GND |
| 24 | XC2 | Y1 pin 3, plus C7 (12pF) to GND |
| 19 | ANT | Net **ANT** — PCB trace antenna, single connection point by design (see [architecture.md](architecture.md#antenna)) |
| 17 | SWDCLK | J1 pin 2 |
| 18 | SWDIO | J1 pin 3 |
| 16 | P0.21 / RESET | J1 pin 1 (~RESET) |
| 31 | DCC | **Unconnected (no-connect flag)** — internal LDO only, no DC/DC inductor used (see [architecture.md](architecture.md#single-shared-power-rail)) |
| 4 | P0.04 | Net **SPI_SCLK** → U2 pin 3 (SCLK) |
| 5 | P0.05 | Net **SPI_SDIO** → U2 pin 2 (SDIO) |
| 6 | P0.06 | Net **SPI_NCS** → U2 pin 5 (NCS) |
| 7 | P0.09 | Net **SENS_MOTION** → U2 pin 8 (MOTION) |
| 8 | P0.10 | Net **SENS_NRESET** → U2 pin 7 (NRESET) |
| 10 | P0.12 | Net **WHEEL_A** → ENC1 pin A |
| 11 | P0.14 | Net **WHEEL_B** → ENC1 pin B |
| 13 | P0.16 | Net **BTN_L** → SW2 pin 1 (COM) |
| 14 | P0.18 | Net **BTN_R** → SW3 pin 1 (COM) |
| 15 | P0.20 | **Unconnected (no-connect flag)** — was BTN_FN → SW4; SW4 (the function button) was removed during PCB layout due to space constraints (see [open-items.md](open-items.md)) |
| 26 | P0.25 | Net **BTN_SCRL** → SW5 pin 1 (COM) — wheel middle-click |
| 2, 3, 12, 27, 28 | P0.00, P0.01, P0.15, P0.28, P0.30 | **Unconnected (no-connect flags)** — reserved spare GPIOs, not used by this design |

The GPIO-to-signal assignment above is this project's own choice (the electrical design left it unconstrained — any of the 16 available GPIOs works for any of the 11 signals). Reassigning any of them is a layout-convenience decision, not a re-design — just relabel the net.

## U2 — PMW3610DM-SUDU (16-pin DIP)

| Pin | Name | Connects to |
|---|---|---|
| 1 | +VCSEL | Direct trace to pin 10, plus a PWR_FLAG (internal laser-driver node, not literally externally powered) |
| 2 | SDIO | Net **SPI_SDIO** |
| 3 | SCLK | Net **SPI_SCLK** |
| 4 | NC | Unconnected (pin is electrically typed no-connect in the symbol) |
| 5 | NCS | Net **SPI_NCS** |
| 6 | VDDIO | Net **+VSYS**, plus C10 (100nF) + C11 (1uF) to GND |
| 7 | NRESET | Net **SENS_NRESET**; R1 (10k) pull-up to +VSYS, populated |
| 8 | MOTION | Net **SENS_MOTION** |
| 9 | VCP | C12 (10uF X7R) + C13 (10nF X7R) to GND, in parallel — per PixArt datasheet Figure 6 |
| 10 | PASS_T | Direct trace to pin 1 |
| 11 | GND | Net **GND** |
| 12 | CP | C14 (100nF X7R) flying cap to pin 13 |
| 13 | CN | C14 (100nF X7R) flying cap to pin 12 |
| 14 | VDD | Net **+VSYS**, plus C8 (10uF X7R) + C9 (100nF) to GND |
| 15 | XYLASER | Direct trace to pin 16 |
| 16 | −VCSEL | Direct trace to pin 15 |

## U3 — TLV61220DBVT (SOT-23-6, adjustable boost)

| Pin | Name | Connects to |
|---|---|---|
| 6 | VBAT | Net **VBAT_SW** — SW1 pin 1, the switched output of the power path (J2 → F1 → Q1 → SW1) |
| 1 | SW | L1, other end to VOUT node |
| 2 | GND | Net **GND** |
| 3 | EN | Tied to VBAT (pin 6) — always-on, no software shutdown |
| 4 | FB | Junction of R2 (to VOUT) and R3 (to GND) |
| 5 | VOUT | Net **+VSYS**; C16 (10uF) to GND at this node; R2 also connects here |

C15 (10uF) sits directly across VBAT to GND, close to pin 6.

## SW1 — JS202011SCQN (DPDT slide switch)

Only section A is used:

| Pin | Connects to |
|---|---|
| 1 (1A) | Net **VBAT_SW** — the switched output, feeding U3 pin 6 (VBAT) and pin 3 (EN) |
| 2 (2A) | Q1 pin 3 (Drain) — the common/input, fed from the protected battery rail |
| 3 (3A) | Unconnected (no-connect flag) — the switch's other throw position |
| 4, 5, 6 (section B) | Unconnected (electrically typed no-connect in the symbol) |

## J2 — battery input (JST B2B-XH-A)

| Pin | Connects to |
|---|---|
| 1 (+) | F1 pin 1 |
| 2 (−) | Net **GND** |

## F1 — short-circuit protection (Littelfuse 0603L010 PPTC fuse)

| Pin | Connects to |
|---|---|
| 1 | J2 pin 1 (+) |
| 2 | Q1 pin 2 (Source) |

## Q1 — reverse-polarity protection (Diodes Inc. DMG2305UXQ, P-channel MOSFET)

| Pin | Name | Connects to |
|---|---|---|
| 1 | Gate | Net **GND** |
| 2 | Source | F1 pin 2 |
| 3 | Drain | SW1 pin 2 (2A) — feeds the switch, which feeds U3 |

## ENC1 — TTC/Kailh-style mouse scroll wheel encoder

No integrated pushbutton — see SW5 below for the middle-click switch
(currently unwired, pending a part swap to a lower-profile switch that
fits under the wheel).
Pin functions (A/B/COM) below are correct per the symbol; **physical
pin positions on the real part are unconfirmed** (see
[`hardware/libraries/vendored/ttc-kailh-mouse-encoder/ATTRIBUTION.md`](../../hardware/libraries/vendored/ttc-kailh-mouse-encoder/ATTRIBUTION.md)).

| Pin | Connects to |
|---|---|
| A | Net **WHEEL_A** |
| B | Net **WHEEL_B** |
| COM | Net **GND** |

## SW5 — wheel middle-click switch (Omron B3U-1000P)

SW5 previously used the same Omron D2FC-F-7N(20M) as SW2/SW3, but that
part's 6.5mm body was too tall to fit underneath the scroll wheel, which
mounts on ENC1's shaft directly above SW5. Replaced 2026-09-27 with the
Omron B3U-1000P (1.6mm height, 2-pin SPST-NO) — see
[`hardware/libraries/vendored/omron-b3u-1000p/ATTRIBUTION.md`](../../hardware/libraries/vendored/omron-b3u-1000p/ATTRIBUTION.md)
for the part-selection detail.

This is a simpler 2-terminal part (no COM/NO/NC distinction like the
D2FC). It has since been rewired to the same electrical behavior as the
old part:

| Pin | Connects to |
|---|---|
| 1 | Net **BTN_SCRL** |
| 2 | Net **GND** |

Both pins are physically symmetric (per the datasheet: "No terminal
numbers are indicated on the Switches"), so this pin assignment was a
free choice. Placed on the PCB next to ENC1 — see
[open-items.md](open-items.md) for the still-unconfirmed physical
mounting height check once the wheel/carriage mechanical design exists.

## J1 — SWD header (Samtec TSW-104-07-T-S)

A plain, unkeyed 4-pin 0.1" header — this pin order is this project's own
choice, not an external standard (there is no universal pinout for a bare
4-pin SWD header the way there is for ARM's shrouded 10-pin Cortex Debug
connector or a Tag-Connect footprint). Anyone wiring a probe to this header
should wire to the labels below, not assume a conventional SWDIO-first
ordering.

| Pin | Signal |
|---|---|
| 1 | nRESET |
| 2 | SWDCLK |
| 3 | SWDIO |
| 4 | GND |

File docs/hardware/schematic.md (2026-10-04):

# Schematic

The schematic lives at [`hardware/custom-wireless-mouse.kicad_sch`](../../hardware/custom-wireless-mouse.kicad_sch) — a single A3 sheet, sectioned into four visually boxed zones rather than split into KiCad hierarchical sub-sheets (a reasonable call at this part count, and how the reference PMW3610 project itself is drawn).

## Sections

- **Power Supply** (top-left) — J2 (battery input connector) → F1 (PPTC resettable fuse) → Q1 (P-channel MOSFET, reverse-polarity ideal-diode protection) → SW1 (power switch) → U3 (TLV61220 boost) → the shared **+VSYS** rail, with the R2/R3 feedback divider and input/output bulk caps.
- **MCU — U1 (nRF52810)** (top-right) — U1 with its decoupling network, 32MHz crystal (Y1) and load caps, SWD header (J1), and the antenna net.
- **Optical Sensor — U2 (PMW3610)** (bottom-left) — U2 with its VDD/VDDIO/VCP decoupling and the CP–CN charge-pump flying cap.
- **User Input — Wheel & Buttons** (bottom-right) — ENC1 (mouse scroll wheel encoder) and SW2, SW3, SW5 (L/R buttons and the wheel's middle-click). SW4 (the function button) was removed during PCB layout — see [open-items.md](open-items.md). See [pinout.md](pinout.md) for pin functions and [open-items.md](open-items.md) for what's still pending on this section (ENC1's footprint is an unconfirmed placeholder).

## Conventions used

- **Global power nets**: `+VSYS` and `GND` are drawn as power symbols (not plain wires threaded across the page), each defined once in
  [`hardware/libraries/local/symbols/local.kicad_sym`](../../hardware/libraries/local/symbols/local.kicad_sym) and reused everywhere that net appears — this is what makes every `+VSYS`/`GND` glyph on the sheet the same electrical net without a single wire connecting them visually.
- **Cross-section signals use net labels, not long wires.** SPI_SCLK, SPI_SDIO, SPI_NCS, SENS_MOTION, SENS_NRESET, WHEEL_A, WHEEL_B, BTN_L, BTN_R, and BTN_SCRL each appear as a short labeled stub at both ends (e.g., at U1's GPIO pin and again at U2 or the relevant switch) rather than as a wire routed physically across the sheet. This is the standard way to keep a schematic legible once wires would otherwise cross section boundaries.
- **PWR_FLAG markers**: KiCad's ERC expects every power net to be "driven" by something it recognizes as a power source. Since several real nodes on this board (the battery's pins, the PMW3610's internal charge-pump nodes) are electrically real but not typed as power sources in their symbols, a small `PWR_FLAG` symbol marks each such net as intentionally externally driven — this is standard KiCad practice, not a workaround specific to this project.
- **No-connect flags** (the small "X" marks) appear only on pins whose electrical type doesn't already declare them unconnected (e.g., U1's spare GPIOs, SW1's unused throw). Pins already typed `no_connect` in their own symbol (U2 pin 4, SW1's section-B pins) are left bare, since adding a flag there is redundant and ERC treats the combination as a contradiction.

## Verification

Checked with `kicad-cli sch erc` against the actual project (not a standalone file — library resolution depends on `hardware/sym-lib-table` and `fp-lib-table`). Result: **0 errors, 0 warnings** (two informational items — `isolated_pin_label` on `ANT`, a single-connection-by-design PCB trace antenna, and a `lib_symbol_mismatch` cache quirk on ENC1 — are excluded in the project's own ERC settings rather than fixed, since neither indicates a real problem).

A full bill of materials with footprints, generated directly from the schematic (`kicad-cli sch export bom`), matches [`docs/hardware/bom.md`](bom.md) exactly.

Every component on the schematic resolves a 3D model — passives via KiCad's own bundled library, the rest via each part's own vendored `3dmodels/` folder. Two of those are substitutes rather than the exact part's own model (U1 uses the real Nordic NRF52810-QCAA-T model; U2 uses a dimensionally-verified PMW3360 substitute, since no PMW3610 model exists anywhere) — see each part's `ATTRIBUTION.md` under `hardware/libraries/vendored/` for the specifics, and [open-items.md](open-items.md) for what that means going into layout.

Every component also carries real sourcing information directly in its schematic fields — Manufacturer, MPN, Distributor, and DPN (distributor part number), visible via `kicad-cli sch export bom --fields Reference,Value,Manufacturer,MPN,Distributor,DPN`. This was independently verified against DigiKey.ca (this board is ordered from Alberta, Canada) as of 2026-09-27; see [bom.md](bom.md) for the full table with distributor links, pricing, and stock status, and [open-items.md](open-items.md) for the two live supply-chain risks this pass surfaced (Q1's lead time, SW2/SW3's discontinuation).

## What isn't drawn on the schematic

- **LENS1** (the PMW3610's matched lens) — a mechanical part with no electrical connection. Noted in a text callout next to U2.

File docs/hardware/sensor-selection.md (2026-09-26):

# Sensor selection

## Evaluation history

Three sensors were evaluated in sequence before landing on the current pick.
Keeping this history because the reasoning matters if sourcing changes again.

### 1. MX8650A (Sigma Micro)

The sensor already present on the original kit board, fully characterized
(complete register map obtained from its datasheet) during the
reverse-engineering phase of this project. Considered for reuse in the new
design since it was already fully understood.

Rejected as the primary pick when its LCSC listing was checked live and
found to 404, with a site-wide LCSC search turning up nothing. Still viable
if desoldered from an existing kit board rather than newly purchased — see
[Desoldering MX8650A as a fallback path](#desoldering-mx8650a-as-a-fallback-path)
below.

### 2. PMW3360DM-T2QU (PixArt)

A gaming-tier sensor with a genuinely public official datasheet (unusual for
PixArt's current lineup, most of which is NDA-gated) and enormous hobbyist
precedent via the QMK/mechanical-keyboard community. Real, in production,
but sourced through regional distributors (EPS Global, Codico) or hobbyist
resellers, not DigiKey/Mouser/LCSC. Considered, then superseded once a
better-fitting part was identified.

### 3. PMW3610DM-SUDU (PixArt) — current pick

Purpose-built as a *low power laser mouse sensor* for wireless applications,
unlike PMW3360 which is a gaming sensor pressed into low-power service. Full
public 8-page datasheet with pin table and register map.

Real open-hardware precedent: [`github.com/siderakb/pmw3610-pcb`](https://github.com/siderakb/pmw3610-pcb)
(CERN-OHL-P licensed, includes an actual KiCad symbol/footprint — vendored
into this repository at [`hardware/libraries/vendored/pmw3610dm-sudu/`](../../hardware/libraries/vendored/pmw3610dm-sudu/))
and mainline Zephyr/ZMK driver support.

User-sourced at ~$4 CAD/unit via AliExpress; cross-checked against two
independent listings (Alibaba, $3 USD at MOQ 2, 475 buyers, 4.8/5.0 rating;
eBay, $6.40 from a Shenzhen seller) to confirm the price wasn't an outlier.

## Desoldering MX8650A as a fallback path

If sourcing PMW3610 falls through, or as a parallel option: the original kit
board's MX8650A can be desoldered and reused, since its complete register
interface is already known from the reverse-engineering phase of this
project.

This requires retargeting the shared rail to either 1.73–1.87V or 2.0–3.5V
(MX8650A's two supported modes) rather than the flat 1.8V assumed for the
PMW3610 path — **the two sensors are not pin- or voltage-compatible, this is
a fork in the design, not an add-on.** The current design (this documentation
set) assumes the PMW3610 path throughout; the MX8650A fallback path has been
discussed but not fully re-specced against a new rail voltage and net list.

## What research ruled out along the way

Documented here because it's genuinely useful to not repeat this work:

- **ADNS-2610 (Broadcom):** a live search suggested "ships today" at DigiKey.
  The actual product page states Part Status: Obsolete, no longer
  manufactured. Any search-snippet claim of stock needs verification against
  the live page, not the snippet — this was the clearest example of why.
- **MX8650A on LCSC:** listing page 404s; site-wide search for the part
  turns up nothing. Likely delisted since it was last checked (it was live
  when its datasheet was first pulled earlier in this project).
- **PixArt's current sensor line generally:** not found on DigiKey, Mouser,
  or LCSC in direct searches. Distributed through regional partners (EPS
  Global, Codico) and hobbyist resellers instead. This appears to be a
  structural gap in that specific market segment (cheap purpose-built
  optical mouse sensors), not a research shortfall.

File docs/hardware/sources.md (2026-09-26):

# Sources

References consulted during the hardware design:

- PixArt PMW3610DM-SUDU datasheet (multiple mirrors located; LCSC-hosted copy
  and `trackballs.eu`-hosted copy both consulted)
- [`github.com/siderakb/pmw3610-pcb`](https://github.com/siderakb/pmw3610-pcb)
  — open-hardware PMW3610 breakout board, BOM and board characteristics
- [`github.com/siderakb/pmw3360-pcb`](https://github.com/siderakb/pmw3360-pcb)
  — sibling project, consulted for comparison during the PMW3360 evaluation
  phase
- Nordic nRF52810 product page and pin table (via DigiKey/LCSC/flux.ai
  listings)
- TI TLV61220DBVT DigiKey product page
- Sigma Micro MX8650A datasheet (from the earlier reverse-engineering phase
  of this project, retained for the fallback path — see
  [sensor selection](sensor-selection.md#desoldering-mx8650a-as-a-fallback-path))
- Marketplace cross-checks: Alibaba and eBay listings for PMW3610DM-SUDU,
  used to validate the user-sourced AliExpress price

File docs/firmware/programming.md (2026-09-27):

# Programming and debugging U1

U1 (Nordic nRF52810) has no USB peripheral, so there is no DFU-over-USB
path — the only way to load firmware or debug the running application is
SWD, through J1 on the board and an external debug probe.

## J1 — SWD header pinout

J1 (Samtec TSW-104-07-T-S) is a plain, unkeyed 4-pin 0.1" header. There is
no external standard pinout for a connector like this — unlike ARM's
shrouded 10-pin Cortex Debug connector or a Tag-Connect footprint, nothing
about this part's mechanical design fixes which pin carries which signal.
The assignment below is this project's own choice, and is what's actually
drawn in the schematic and printed on the symbol/silkscreen:

| Pin | Signal |
|---|---|
| 1 | nRESET |
| 2 | SWDCLK |
| 3 | SWDIO |
| 4 | GND |

Wire a probe to these labels directly. There is no VTref/VTG sense pin on
this header, so whichever probe is used needs its target voltage set
manually (this board runs at the boosted **+VSYS** rail, ~1.89V-to-boost-set
on the low side but presented to U1 at the regulated system voltage —
confirm against [`docs/hardware/bom.md`](../hardware/bom.md) at the bench)
rather than relying on auto-detection.

## Toolchain integration

This project's firmware is built on nRF Connect SDK (Zephyr's `west`).
`west flash` supports several interchangeable runners — `nrfjprog`/`jlink`,
`pyocd`, and `openocd` — selected with `west flash -r <runner>`. This means
any CMSIS-DAP probe (which uses `pyocd` or `openocd`) or a J-Link (which
uses `jlink`/`nrfjprog`) plugs into the same build workflow without needing
a different SDK or toolchain per probe.

## Debug probe options

### ST-Link V3SET — already owned, untested against this board

An ST-Link V3SET (board silkscreen `MB1440B`) is available for this
project. SWD itself is a generic ARM protocol, so it can in principle
reach any Cortex-M target — but ST-Link V3's own firmware is documented to
perform a device-ID check and, in many reported cases, simply refuses to
attach to a non-ST target. This is a known, tracked issue (OpenOCD ticket
#275, "ST-Link v3 refuses to work with non-ST targets"), not a one-off
report. Community workarounds (specific older firmware revisions,
specific OpenOCD development builds) exist but are inconsistent and
unofficial.

Practical guidance: test it with **OpenOCD**, not ST's own
STM32CubeProgrammer/ST-Link Utility (which will almost certainly refuse a
non-ST device outright). The V3SET kit's MB1440 adapter board exposes an
STDC14 (14-pin, 1.27mm-pitch) connector, not a simple 4-pin header, so
reaching J1 needs jumper wires or a breakout from the individual
T_SWDIO/T_SWCLK/T_NRST/GND signals on that connector — a wiring task, not a
blocker on its own.

### Cheaper alternatives, if the ST-Link V3SET doesn't attach

Ranked cheapest to most reliable, all independently confirmed (not just
assumed) to work against nRF52-family targets specifically:

1. **ST-Link V2 clone (~$2, AliExpress/eBay) + OpenOCD.** Unlike V3,
   ST-Link V2 doesn't have the device-restriction firmware issue, and
   there's a specific documented walkthrough for flashing an nRF52 this
   way. Trade-off: unbranded clone hardware, OpenOCD-only (no official
   tooling).
2. **Blue Pill (STM32F103, ~$2-8) flashed with Black Magic Probe
   firmware.** Nordic's own DevZone blog has a post specifically titled
   "Flashing and debugging nRF51/52 with a cheap Black Magic Probe
   compatible SWD programmer" — this exact cheap-clone-to-nRF5x path is
   Nordic-documented. Black Magic Probe runs its own GDB server on-chip,
   so OpenOCD isn't needed in the middle.
3. **A plain Raspberry Pi Pico (~$4-5) flashed with the open-source
   `debugprobe` firmware.** Genuine, reliable hardware (not a clone),
   official Raspberry Pi Foundation firmware, confirmed working against
   nRF52 targets. Requires soldering/wiring your own SWD leads and
   flashing the firmware yourself.
4. **The official Raspberry Pi Debug Probe (~$12).** Same firmware/approach
   as above, pre-built and cased with a ready-made SWD cable — no DIY
   wiring or flashing required. Best cost-to-hassle ratio of the cheap
   options.
5. **Segger J-Link EDU Mini (~$20).** The only option with zero
   compatibility guesswork, since `nrfjprog` (nRF Connect SDK's native
   tool) is built around J-Link specifically. Licensed **non-commercial /
   educational use only.**

## Sources

- [OpenOCD ticket #275 — "ST-Link v3 refuses to work with non-ST targets"](https://sourceforge.net/p/openocd/tickets/275/)
- [STMicroelectronics Community — "Is the STLINK-V3SET locked to only ST MCUs?"](https://community.st.com/stm32-mcus-boards-and-hardware-tools-26/is-the-stlink-v3set-locked-to-only-st-mcus-28160)
- [STLINK-V3SET User Manual (UM2448)](https://www.st.com/resource/en/user_manual/um2448-stlinkv3set-debuggerprogrammer-for-stm8-and-stm32-stmicroelectronics.pdf)
- [pcbreflux — nRF52832 first steps with ST-Link V2 and OpenOCD](https://pcbreflux.blogspot.com/2016/09/nrf52832-first-steps-with-st-link-v2.html)
- [Industrial Monitor Direct — Programming nRF52810 with ST-LINK V2 via OpenOCD](https://industrialmonitordirect.com/blogs/knowledgebase/programming-nrf52810-with-st-link-v2-openocd-configuration)
- [Nordic DevZone Blog — Flashing and debugging nRF51/52 with a cheap Black Magic Probe compatible SWD programmer](https://devzone.nordicsemi.com/nordic/nordic-blog/b/blog/posts/flashing-and-debugging-nrf5152-with-a-cheap-blackm)
- [gojimmypi — Converting a Blue Pill STM32F103 to a Black Magic Probe](https://gojimmypi.github.io/BluePill-STM32F103-to-BlackMagic-Probe/)
- [jsan.ch — Programming an nRF52 with the Raspberry Pi Debug Probe](https://jsan.ch/posts/2023/09/programming-an-nrf52-with-the-raspberry-pi-debug-probe/)
- [Raspberry Pi — Debug Probe product page](https://www.raspberrypi.com/products/debug-probe/)
- [Pimoroni — PicoProbe PCB kit ($8)](https://shop.pimoroni.com/en-us/products/picoprobe-pcb-kit)
- [SEGGER — J-Link EDU Mini](https://www.segger.com/products/debug-probes/j-link/models/j-link-edu-mini/)
- [nRF Connect SDK docs — Programming an application (runner support: nrfjprog, jlink, pyocd, openocd)](https://nrfconnectdocs.nordicsemi.com/ncs/latest/nrf/app_dev/programming.html)

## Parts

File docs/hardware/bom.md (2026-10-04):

# Bill of materials

**Status:** fully audited against real, currently-orderable distributor listings — every line below is a specific manufacturer part number with a live DigiKey.ca (or, for the two parts absent from standard distribution, a named reseller) listing, confirmed in stock or on a known restock date as of **2026-09-27**. Every part also has a symbol, footprint, and 3D model in the project. See [`docs/hardware/schematic.md`](schematic.md) for how these are wired together, and [`docs/hardware/open-items.md`](open-items.md) for anything still unconfirmed.

Sourcing was checked against Canadian-facing distributors — primarily DigiKey.ca, with Mouser.ca as a secondary source where DigiKey.ca data was unavailable — since this board is built and ordered from Alberta, Canada. Prices below are DigiKey.ca CAD list price at low quantity (1-25 pcs) unless noted; re-check before placing a purchase order, since stock and pricing move week to week.

## Major components

**Note:** SW4 (the dedicated function/DPI button) was removed from the design during PCB layout — the board didn't have room for a fourth button footprint once routing was underway. See [open-items.md](open-items.md) and [architecture.md](architecture.md#dpi-control).

| Ref | Part | Manufacturer | Package | Qty | Distributor / SKU | Price (CAD) | Stock status |
|---|---|---|---|---|---|---|---|
| U1 | **nRF52810-QCAA-T** | Nordic Semiconductor | 32-QFN, 5x5mm, 0.5mm pitch | 1 | DigiKey.ca [4823-NRF52810-QCAA-T-ND](https://www.digikey.ca/en/products/detail/nordic-semiconductor-asa/NRF52810-QCAA-T/7725411) | $5.02 | **Active, in stock** (8,643 units) |
| U2 | **PMW3610DM-SUDU** (+ LM18-LSI lens) | PixArt Imaging | 16-pin DIP | 1 | [AliExpress, item 1005007118767775](https://de.aliexpress.com/item/1005007118767775.html) — "New and Original PMW3610DM-SUDU + LM18-LSI DIP" | ~CAD $8.64 (per your own listing check) | Confirmed live listing, ships from a specialty reseller — this part is genuinely absent from DigiKey/Mouser/LCSC, so this is the correct purchasing channel, not a fallback |
| LENS1 | **LM18-LSI** | PixArt Imaging | optical lens | 1 | Bundled with the U2 listing above, not sold separately | — | Same listing as U2 |
| U3 | **TLV61220DBVT** | Texas Instruments | SOT-23-6 | 1 | DigiKey.ca [296-43576-1-ND](https://www.digikey.ca/en/products/detail/texas-instruments/TLV61220DBVT/3588875) | $2.06 | **Active, in stock** (1,612 units) |
| Y1 | **NX2016SA-32MHZ-EXS00A-CS06654** | NDK America | 4-pad SMD, 2.0x1.6mm | 1 | DigiKey.ca [644-CS06654-32MCT-ND](https://www.digikey.ca/en/products/detail/ndk-america-inc/NX2016SA-32MHZ-EXS00A-CS06654/9172029) | $0.76 | **Active, in stock** (102,352 units). 32MHz, 8pF load capacitance, ±10ppm tolerance — matches Nordic's own reference circuit. This is the full, correct orderable part number for the generic "NX2016SA-32MHZ" family designation. |
| ENC1 | TTC/Kailh-style **mouse scroll wheel encoder** | TTC or Kailh (mod-market) | THT, ~1.74mm D-shaft, body height TBD (5-14mm depending on wheel) | 1 | [Ausmodshop — Kailh mouse scroll wheel encoder](https://ausmodshop.com/products/kailh-mouse-scroll-wheel-encoder) ($4.95 AUD, 7/8/10/11/12/13/14mm in stock) or [TTC Gold variant](https://ausmodshop.com/products/ttc-gold-mouse-scroll-wheel-encoder) ($5.95 AUD, 7/8/9mm in stock) | ~$4-6 AUD | Confirmed live stock at time of writing. No manufacturer datasheet exists for this part class (mod-market only), so footprint remains an unconfirmed placeholder — see [open items](open-items.md). No standard-distributor substitute exists at this shaft diameter (checked Bourns PEC11/12 and Alps EC11, both ~6mm shafts). |
| SW1 | **JS202011SCQN** | C&K (Littelfuse) | SMD slide switch, DPDT | 1 | DigiKey.ca [401-2002-1-ND](https://www.digikey.ca/en/products/detail/c-k/JS202011SCQN/1640098) | $1.28 | **Active, in stock** (100,379 units) |
| SW2, SW3 | **D2FC-F-7N(20M)** | Omron | THT, 12.8x5.8x6.5mm SPDT snap-action | 2 | DigiKey.ca [39-D2FC-F-7N(20M)-ND](https://www.digikey.ca/en/products/detail/omron-electronics-inc-emc-div/D2FC-F-7N-20M/20484121) | $0.86 | **Manufacturer-discontinued (EOL)** — DigiKey's own listing states it will no longer be stocked once depleted. 4,658 units remain at DigiKey.ca as of this pass; sufficient for a small-batch build, but buy now rather than treat this as a long-term-available part. No same-footprint active replacement was found at DigiKey/Mouser — this exact body/pin layout is otherwise a mod-market-only part (Kailh/Huano clones). |
| SW5 | **B3U-1000P** | Omron | SMD, 3.0x2.5mm, 1.6mm height, SPST-NO tactile | 1 | DigiKey.ca [SW1020CT-ND](https://www.digikey.ca/en/products/detail/omron-electronics-inc-emc-div/B3U-1000P/1534338) | $1.83 | **Active, in stock** (129,510 units). Middle-click switch for the scroll wheel — deliberately a different part from SW2-4: the D2FC-F-7N(20M)'s 6.5mm body doesn't fit under the scroll wheel, which mounts on ENC1's shaft directly above SW5. Swapped 2026-09-27 for this ultra-low-profile part instead — see [`hardware/libraries/vendored/omron-b3u-1000p/ATTRIBUTION.md`](../../hardware/libraries/vendored/omron-b3u-1000p/ATTRIBUTION.md) for the full candidate comparison. 2-pin SPST (no COM/NO/NC distinction like the D2FC) — rewired (pin 1 → BTN_SCRL, pin 2 → GND, matching the old part's COM/GND mapping) and re-placed on the PCB next to ENC1. |
| J1 | **TSW-104-07-T-S** | Samtec | 4-pin, 2.54mm pitch, THT vertical | 1 | DigiKey.ca [612-TSW-104-07-T-S-ND](https://www.digikey.ca/en/products/detail/samtec-inc/TSW-104-07-T-S/1101620) | $0.23 | **Active, in stock** (2,855 units + 1,744 factory stock). Pin assignment (this project's own choice — see [pinout.md](pinout.md#j1--swd-header-samtec-tsw-104-07-t-s)): 1=nRESET, 2=SWDCLK, 3=SWDIO, 4=GND. |
| J2 | **B2B-XH-A(LF)(SN)** | JST | 2-position, 2.50mm pitch, THT vertical | 1 | DigiKey.ca [455-B2B-XH-A-ND](https://www.digikey.ca/en/products/detail/jst-sales-america-inc/B2B-XH-A-LF-SN/1651045) | $0.15 | **Active, in stock** (303,971 units). "B2B-XH-A(LF)(SN)" is the full orderable catalog number — the bare "B2B-XH-A" used in earlier passes is JST's family name, not a purchasable SKU. This is the vertical/top-entry variant; JST also sells a right-angle version under a different part number (B2B-XH-AS), not used here. Battery-side mating harness (single-AAA holder + JST XH pigtail) sourced separately — see [open-items.md](open-items.md) item 7. |
| F1 | **0603L010YR** | Littelfuse | 0603 SMD, PPTC resettable fuse | 1 | DigiKey.ca [F2900CT-ND](https://www.digikey.ca/en/products/detail/littelfuse-inc/0603L010YR/1920183) | $2.10 | **Active, in stock** (120,808 units). 0.10A hold / 0.30A trip, 15V max. "0603L010YR" is the full orderable part number (Y = tape-and-reel qty code, R = packaging) — "0603L010" alone is the family designation, not a purchasable SKU. |
| Q1 | **DMG2305UXQ-7** | Diodes Incorporated | SOT-23, P-channel MOSFET | 1 | DigiKey.ca [31-DMG2305UXQ-7CT-ND](https://www.digikey.ca/en/products/detail/diodes-incorporated/DMG2305UXQ-7/5768821) | $0.70 | **Active, in stock** (17 units — thin, sufficient for a small build; re-check before a larger run). AEC-Q101 automotive-qualified. See the note below — this replaces the originally-specified DMP2035U-7, and is a genuine improvement, not just a stock swap. |

## nRF52810 support passives

| Ref | Value | Manufacturer | MPN | Package | Qty | Distributor / SKU | Price (CAD) | Stock |
|---|---|---|---|---|---|---|---|---|
| C1–C4 | 100nF | Yageo | CC0603KRX7R9BB104 | 0603 | 4 | DigiKey.ca [311-1344-1-ND](https://www.digikey.ca/en/products/detail/yageo/CC0603KRX7R9BB104/2103082) | $0.07 | On backorder at DigiKey.ca as of this pass (0 on hand; 4,000 due 2026-09-28 — effectively next-day). One per DEC1–DEC4 pin per Nordic's own regulator decoupling spec, not a shared net. |
| C5 | 1uF | Yageo | CC0603KRX5R6BB105 | 0603 | 1 | DigiKey.ca [311-1443-1-ND](https://www.digikey.ca/en/products/detail/yageo/CC0603KRX5R6BB105/2833608) | $0.10 | **In stock** (34,677 units). VDD bulk decoupling. |
| C6, C7 | 12pF NP0/C0G | Yageo | CC0402FRNPO9BN120 | 0402 | 2 | DigiKey.ca [311-1641-1-ND](https://www.digikey.ca/en/products/detail/yageo/CC0402FRNPO9BN120/5195050) | $0.06 | On backorder at DigiKey.ca as of this pass (0 on hand; 10,000 due 2026-10-12). Y1 load caps — matches Nordic's own published reference circuit (8pF crystal, 12pF load caps). |

## PMW3610 support passives

Values sourced from `github.com/siderakb/pmw3610-pcb`'s real KiCad schematic, cross-checked against PixArt's own datasheet Figure 6.

| Ref | Value | Manufacturer | MPN | Package | Qty | Distributor / SKU | Price (CAD) | Stock | Function |
|---|---|---|---|---|---|---|---|---|---|
| C8 | 10uF X5R | Murata | GRT188R61A106KE13J | 0603 | 1 | DigiKey.ca [490-GRT188R61A106KE13JCT-ND](https://www.digikey.ca/en/products/detail/murata-electronics/GRT188R61A106KE13J/13904783) | ~$0.17-0.26 | **In stock** (458 units) | VDD (pin 14) bulk decoupling. |
| C9 | 100nF | Yageo | CC0603KRX7R9BB104 | 0603 | 1 | Same as C1-C4 above | $0.07 | Backorder, restock 2026-09-28 | VDD (pin 14) decoupling, parallel with C8. |
| C10 | 100nF | Yageo | CC0603KRX7R9BB104 | 0603 | 1 | Same as C1-C4 above | $0.07 | Backorder, restock 2026-09-28 | VDDIO (pin 6) decoupling. |
| C11 | 1uF | Yageo | CC0603KRX5R6BB105 | 0603 | 1 | Same as C5 above | $0.10 | In stock | VDDIO (pin 6) bulk decoupling, parallel with C10. |
| C12 | 10uF X5R | Murata | GRT188R61A106KE13J | 0603 | 1 | Same as C8 above | ~$0.17-0.26 | In stock | VCP (pin 9) to GND — charge-pump reservoir, bulk. Per PixArt's own Figure 6, which specifies two parallel caps here (bulk + HF). |
| C13 | 10nF X7R | Yageo | CC0603KRX7R9BB103 | 0603 | 1 | DigiKey.ca [311-1085-1-ND](https://www.digikey.ca/en/products/detail/yageo/CC0603KRX7R9BB103/302819) | $0.05 | **In stock** (499,523 units) | VCP (pin 9) to GND — charge-pump reservoir, HF, parallel with C12. |
| C14 | 100nF X7R | Yageo | CC0603KRX7R9BB104 | 0603 | 1 | Same as C1-C4 above | $0.07 | Backorder, restock 2026-09-28 | CP(12)–CN(13) flying cap. |
| R1 | 10k, 1% | Yageo | RC0603FR-0710KL | 0603 | 1 | DigiKey.ca [311-10.0KHRCT-ND](https://www.digikey.ca/en/products/detail/yageo/RC0603FR-0710KL/726880) | $0.02 | **In stock** (659,892 units) | NRESET (pin 7) pull-up to +VSYS. |

## Boost regulator support passives

Pulled directly from TI's TLV61220 datasheet (SLVSB53A) application circuit.

| Ref | Value | Manufacturer | MPN | Package | Qty | Distributor / SKU | Price (CAD) | Stock |
|---|---|---|---|---|---|---|---|---|
| L1 | 4.7uH | Murata | **1269AS-H-4R7M=P2** | 2.5×2.0×1.0mm ("1008"/2520 metric) | 1 | DigiKey.ca [490-10577-1-ND](https://www.digikey.ca/en/products/detail/murata-electronics-north-america/1269AS-H-4R7M=P2/5272033) | $0.41 | **Active, in stock** (19,253 units). Toko's original inductor line (this part carries the legacy "1269AS" designation) was absorbed into Murata; the "=P2" packaging suffix is Murata/Toko's own separator convention, not a typo. |
| C15 (Cin) | 10uF, X5R | Murata | GRT188R61A106KE13J | 0603 | 1 | Same as C8 above | ~$0.17-0.26 | In stock | |
| C16 (Cout) | 10uF, X5R | Murata | GRT188R61A106KE13J | 0603 | 1 | Same as C8 above | ~$0.17-0.26 | In stock | |
| R2 (VOUT-to-FB) | **499kΩ, 1%** | Yageo | RC0603FR-07499KL | 0603 | 1 | DigiKey.ca [311-499KHRCT-ND](https://www.digikey.ca/en/products/detail/yageo/RC0603FR-07499KL/727267) | $0.02 | **In stock** (271,014 units). Confirmed standard E96 value. |
| R3 (FB-to-GND) | **180kΩ, 1%** | Yageo | RC0603FR-07180KL | 0603 | 1 | DigiKey.ca [311-180KHRCT-ND](https://www.digikey.ca/en/products/detail/yageo/RC0603FR-07180KL/726995) | $0.02 | **In stock** (35,626 units). Confirmed standard E96 value. |

### L1 footprint corrected during this pass

The real Murata 1269AS-H-4R7M=P2 body is **2.5 × 2.0 × 1.0mm** ("1008" imperial / 2520 metric case size). The schematic previously carried a placeholder footprint (`Inductor_SMD:L_1210_3225Metric`, a 3.2 × 2.5mm body) — oversized relative to the real part. This has been corrected to `Inductor_SMD:L_1008_2520Metric`, KiCad's own bundled footprint for this exact case size.

### Boost output voltage

VOUT = VFB × (1 + R2/R3), VFB typical 500mV. With R3 = 180kΩ, R2 = 499kΩ: **VOUT ≈ 1.89V** — comfortably clear of TLV61220's 1.8V absolute-minimum floor and clear of U2's 2.1V ceiling.

## Q1 — replaced DMP2035U-7 with DMG2305UXQ-7 (2026-09-27)

This design originally specified Diodes Incorporated's **DMP2035U-7**, an Active part that turned out to be out of stock at both DigiKey.ca and Mouser with a ~40-week manufacturer lead time. Three in-stock alternatives were checked against Diodes' own datasheets before deciding:

- **AO3401A** (Alpha & Omega Semiconductor, 1,831,820 units in stock at DigiKey.ca): VGS(TH) max **-1.3V** — worse than DMP2035U's -1.0V. Rejected: this board's reverse-polarity protection circuit has a documented low-battery corner case (see [open-items.md](open-items.md)), and a higher-magnitude threshold makes it worse, not better.
- **AO3415A** / **AO3415** (same family): both NRND or fully Obsolete at DigiKey.ca. Rejected on those grounds alone.
- **DMG2305UXQ-7** (Diodes Incorporated, 17 units in stock at DigiKey.ca): VGS(TH) max **-0.9V** — *better* than DMP2035U's -1.0V, narrowing the low-battery corner case rather than widening it. AEC-Q101 automotive-qualified (not a requirement here, but not a downside). **Selected.**

All three candidates use the identical SOT-23-3 Gate-Source-Drain pinout as DMP2035U-7, so this was a pure component substitution — no footprint or schematic rewiring was needed. The vendored library was renamed from `diodes-dmp2035u`/`DMP2035U` to `diodes-dmg2305uxq`/`DMG2305UXQ` (symbol, footprint, 3D model, and datasheet all updated to match); see [that library's ATTRIBUTION.md](../../hardware/libraries/vendored/diodes-dmg2305uxq/ATTRIBUTION.md) for the full comparison. ERC re-confirmed clean (0 violations) after the swap.

## Corrections made during this pass's audit

1. **Y1's full orderable part number.** The previous pass specified "NX2016SA-32MHZ-STD-CZS-5" (an LCSC-side catalog string). The real DigiKey.ca-orderable NDK America part meeting the same spec (32MHz, 8pF, ±10ppm) is **NX2016SA-32MHZ-EXS00A-CS06654**.
2. **F1's full orderable part number.** "0603L010" is Littelfuse's family designation; the orderable part is **0603L010YR**.
3. **J2's full orderable part number.** "B2B-XH-A" is JST's family name; the orderable part is **B2B-XH-A(LF)(SN)**.
4. **L1's footprint.** Corrected from an oversized placeholder to the real part's 2520-metric case size (see above).
5. **Q1's full orderable part number.** "DMP2035U" is the family designation; **DMP2035U-7** is the orderable 7"-reel part.

All five are reflected directly in the schematic's component fields (Manufacturer/MPN/Distributor/DPN, visible via `kicad-cli sch export bom`) as well as in the tables above.

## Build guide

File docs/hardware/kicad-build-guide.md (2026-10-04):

# KiCad build guidance

The schematic (`hardware/custom-wireless-mouse.kicad_sch`) is done — see
[schematic.md](schematic.md) for how it's organized and
[open-items.md](open-items.md) for what's still open before layout. This
records the order it was actually built in and the reasoning per part, for
anyone extending or re-deriving it.

1. **U1 (nRF52810) and its support circuit first** — symbol and footprint
   vendored from KiCad's own official `MCU_Nordic` / `Package_DFN_QFN`
   libraries (see [`hardware/libraries/vendored/nordic-nrf52810-qcxx/`](../../hardware/libraries/vendored/nordic-nrf52810-qcxx/)),
   rather than relying on KiCad's global library at build time — the goal is
   a project that opens identically on any KiCad 10 install, not one that
   depends on whichever library version happens to be bundled locally.
2. **U2 (PMW3610) and its charge-pump network** — the vendored symbol and
   footprint at
   [`hardware/libraries/vendored/pmw3610dm-sudu/`](../../hardware/libraries/vendored/pmw3610dm-sudu/)
   (sourced from `github.com/siderakb/pmw3610-pcb`, CERN-OHL-P licensed)
   rather than a new 16-pin DIP symbol drawn from the datasheet. The
   charge-pump values (C12/C13/C14) were confirmed by reading that project's
   actual `.kicad_sch` file directly and cross-checking against PixArt's own
   datasheet Figure 6 — see [bom.md](bom.md) for what that changed.
3. **U3 (boost regulator) and passives** — no ready-made symbol existed for
   this exact part anywhere checked, so it was hand-drawn directly from TI's
   published pinout table (a datasheet's pin function list is factual
   information, not copyrightable expression, so this is an original symbol
   rather than a copy of anyone's library). Footprint is KiCad's own
   bundled SOT-23-6, vendored in alongside it.
4. **Switches, encoder, SWD header** — SW1 (power switch) and J1 (SWD
   header) use real footprints from KiCad's or DigiKey's official
   libraries. SW2/SW3 (L/R buttons) use a hand-drawn footprint for the
   Omron D2FC-F-7N(20M) — the de-facto DIY mouse-switch aftermarket
   standard body, chosen deliberately over an SMD tactile switch so common
   2-pin/3-pin swap-in switches (Kailh GM series, Huano, TTC) solder
   directly onto this board. SW5 (the wheel's middle-click) uses a
   different, much lower-profile part (Omron B3U-1000P) to clear the
   scroll wheel mounted above it — see [open-items.md](open-items.md).
   SW4 (the function button) was removed during layout; there is no
   fourth button on this board. ENC1 (the scroll wheel
   encoder) is a TTC/Kailh-style mouse encoder with an explicitly
   unconfirmed placeholder footprint, since no manufacturer datasheet
   exists for this part class — see
   [`hardware/libraries/vendored/ttc-kailh-mouse-encoder/ATTRIBUTION.md`](../../hardware/libraries/vendored/ttc-kailh-mouse-encoder/ATTRIBUTION.md).
   Every vendor directory's `ATTRIBUTION.md` says which case applies and
   why that specific part was picked over its closest sibling.
5. **Battery input and protection (J2, F1, Q1)** — a JST B2B-XH-A header
   (J2) accepts a pre-crimped harness from an external battery pack, in
   series with a Littelfuse 0603L010 PPTC resettable fuse (F1, short-circuit
   protection) and a Diodes Inc. DMG2305UXQ P-channel MOSFET (Q1, wired as a
   high-side ideal diode for reverse-polarity protection) ahead of SW1 and
   U3. Symbols, footprints, and 3D models for all three are vendored from
   KiCad's own official libraries; see each part's `ATTRIBUTION.md` under
   [`hardware/libraries/vendored/`](../../hardware/libraries/vendored/).

See [`hardware/README.md`](../../hardware/README.md) for the project's
overall library policy and folder layout.

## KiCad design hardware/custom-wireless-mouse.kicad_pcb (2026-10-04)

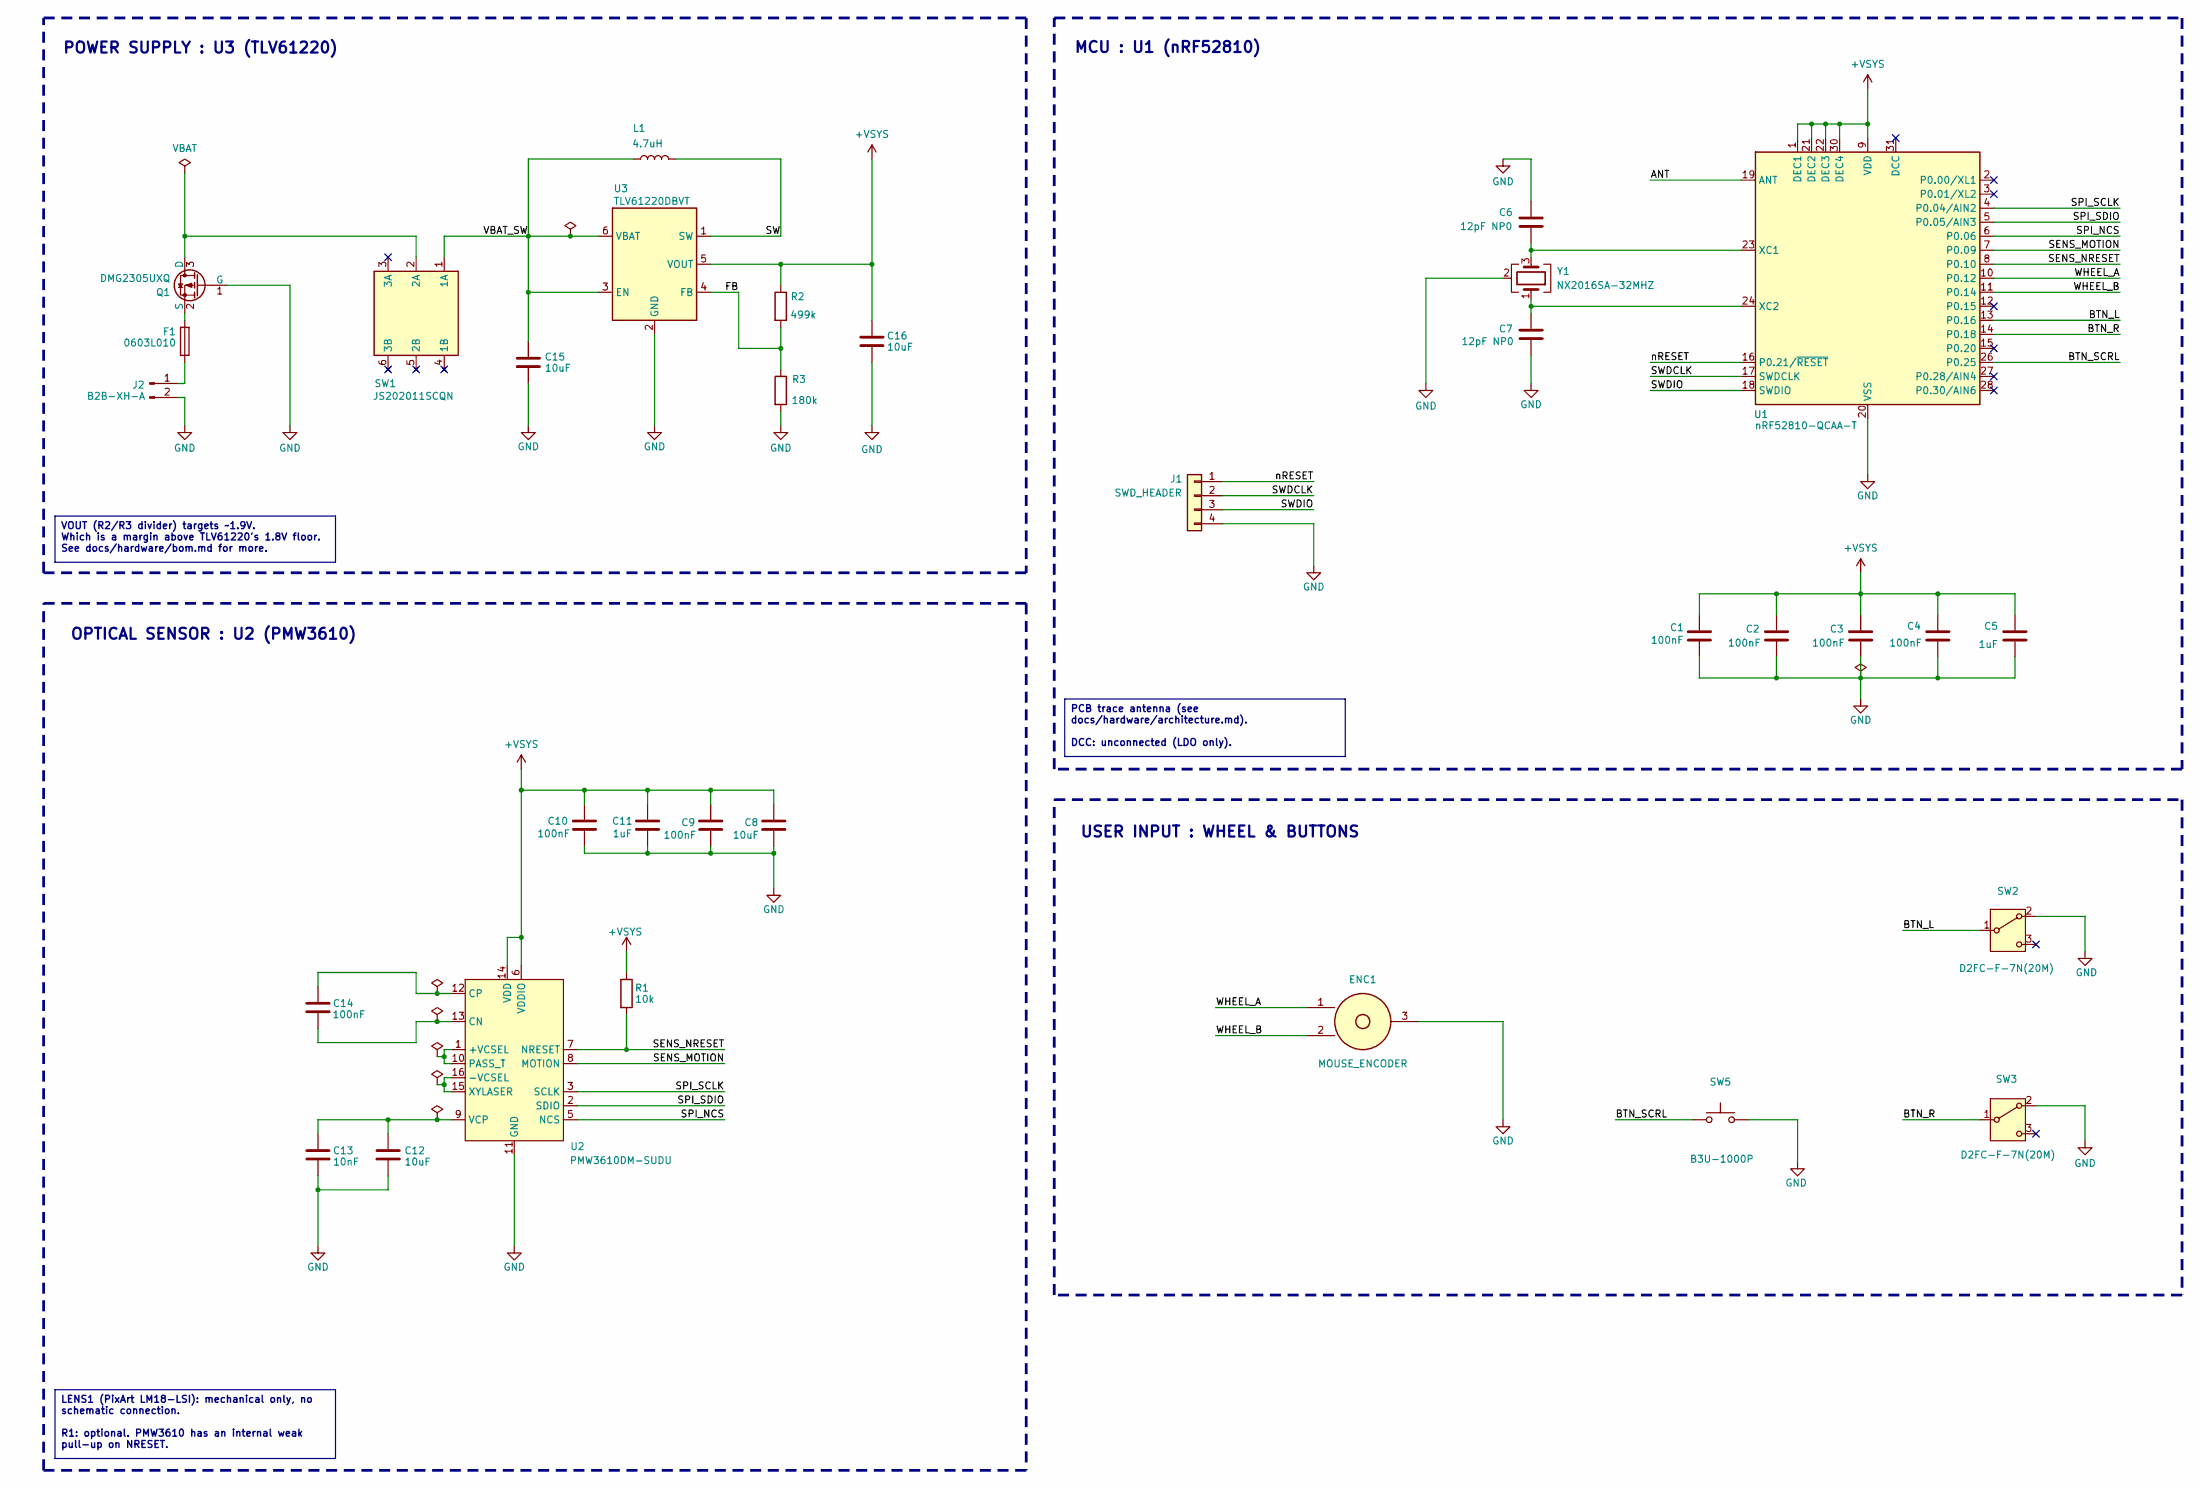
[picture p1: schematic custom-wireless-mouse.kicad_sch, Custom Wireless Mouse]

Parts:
C1, C2, C3, C4, C9, C10, C14: 100nF; C_0603_1608Metric; MPN CC0603KRX7R9BB104
C5, C11: 1uF; C_0603_1608Metric; MPN CC0603KRX5R6BB105
C6, C7: 12pF NP0; C_0402_1005Metric; MPN CC0402FRNPO9BN120
C8, C12, C15, C16: 10uF; C_0603_1608Metric; MPN GRT188R61A106KE13J
C13: 10nF; C_0603_1608Metric; MPN CC0603KRX7R9BB103
ENC1: MOUSE_ENCODER; encoder-tht-placeholder-mouse-wheel; MPN Mouse scroll encoder, 7-9mm body height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
F1: 0603L010; fuse-0603-littelfuse-0603l010; MPN 0603L010YR
J1: SWD_HEADER; pinheader-1x04-p2.54mm-vertical; MPN TSW-104-07-T-S
J2: B2B-XH-A; battery-conn-jst-b2b-xh-a; MPN B2B-XH-A(LF)(SN)
L1: 4.7uH; L_1008_2520Metric; MPN 1269AS-H-4R7M=P2
Q1: DMG2305UXQ; sot-23-dmg2305uxq; MPN DMG2305UXQ-7
R1: 10k; R_0603_1608Metric; MPN RC0603FR-0710KL
R2: 499k; R_0603_1608Metric; MPN RC0603FR-07499KL
R3: 180k; R_0603_1608Metric; MPN RC0603FR-07180KL
SW1: JS202011SCQN; switch-slide-js202011scqn; MPN JS202011SCQN
SW2, SW3: D2FC-F-7N(20M); switch-tht-omron-d2fc-f-7n; MPN D2FC-F-7N(20M)
SW5: B3U-1000P; switch-smd-omron-b3u-1000p; MPN B3U-1000P
U1: nRF52810-QCAA-T; qfn-32-1ep-5x5mm-p0.5mm-ep3.6x3.6mm; MPN nRF52810-QCAA-T
U2: PMW3610DM-SUDU; pmw3610dm-sudu-16-pin; MPN PMW3610DM-SUDU
U3: TLV61220DBVT; sot-23-6; MPN TLV61220DBVT
Y1: NX2016SA-32MHZ; crystal-smd-2016-4pin-2.0x1.6mm; MPN NX2016SA-32MHZ-EXS00A-CS06654

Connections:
+VSYS: C1.1, C2.1, C3.1, C4.1, C5.1, C8.1, C9.1, C10.1, C11.1, C16.1, R1.1, R2.1, U1.1 (DEC1), U1.9 (VDD), U1.21 (DEC2), U1.22 (DEC3), U1.25 (VDD), U1.30 (DEC4), U1.32 (VDD), U2.6 (VDDIO), U2.14 (VDD), U3.5 (VOUT)
/ANT: U1.19 (ANT)
/BTN_L: SW2.1 (COM), U1.13 (P0.16)
/BTN_R: SW3.1 (COM), U1.14 (P0.18)
/BTN_SCRL: SW5.1, U1.26 (P0.25)
/FB: R2.2, R3.1, U3.4 (FB)
/SENS_MOTION: U1.7 (P0.09), U2.8 (MOTION)
/SENS_NRESET: R1.2, U1.8 (P0.10), U2.7 (NRESET)
/SPI_NCS: U1.6 (P0.06), U2.5 (NCS)
/SPI_SCLK: U1.4 (P0.04/AIN2), U2.3 (SCLK)
/SPI_SDIO: U1.5 (P0.05/AIN3), U2.2 (SDIO)
/SW: L1.2, U3.1 (SW)
/SWDCLK: J1.2 (SWDCLK), U1.17 (SWDCLK)
/SWDIO: J1.3 (GND), U1.18 (SWDIO)
/VBAT_SW: C15.1, L1.1, SW1.1 (1A), U3.3 (EN), U3.6 (VBAT)
/WHEEL_A: ENC1.1 (A), U1.10 (P0.12)
/WHEEL_B: ENC1.2 (B), U1.11 (P0.14)
/nRESET: J1.1 (SWDIO), U1.16 (P0.21/~RESET)
GND: C1.2, C2.2, C3.2, C4.2, C5.2, C6.1, C7.2, C8.2, C9.2, C10.2, C11.2, C12.2, C13.2, C15.2, C16.2, ENC1.3 (COM), J1.4 (~RESET), J2.2 (-), Q1.1 (G), R3.2, SW2.2 (NO), SW3.2 (NO), SW5.2, U1.20 (VSS), U1.29 (VSS), U1.33 (VSS), U2.11 (GND), U3.2 (GND), Y1.2 (G), Y1.4 (G)
unnamed: F1.1, J2.1 (+)
unnamed: Q1.3 (D), SW1.2 (2A)
unnamed: F1.2, Q1.2 (S)
unnamed: C6.2, U1.23 (XC1), Y1.3
unnamed: C7.1, U1.24 (XC2), Y1.1
unnamed: U2.1 (+VCSEL), U2.10 (PASS_T)
unnamed: U2.15 (XYLASER), U2.16 (-VCSEL)
unnamed: C14.2, U2.13 (CN)
unnamed: C14.1, U2.12 (CP)
unnamed: C12.1, C13.1, U2.9 (VCP)

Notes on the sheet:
USER INPUT : WHEEL & BUTTONS
POWER SUPPLY : U3 (TLV61220)
MCU : U1 (nRF52810)
OPTICAL SENSOR : U2 (PMW3610)
LENS1 (PixArt LM18-LSI): mechanical only, no schematic connection. R1: optional. PMW3610 has an internal weak pull-up on NRESET.
PCB trace antenna (see docs/hardware/architecture.md). DCC: unconnected (LDO only).
VOUT (R2/R3 divider) targets ~1.9V. Which is a margin above TLV61220's 1.8V floor. See docs/hardware/bom.md for more.

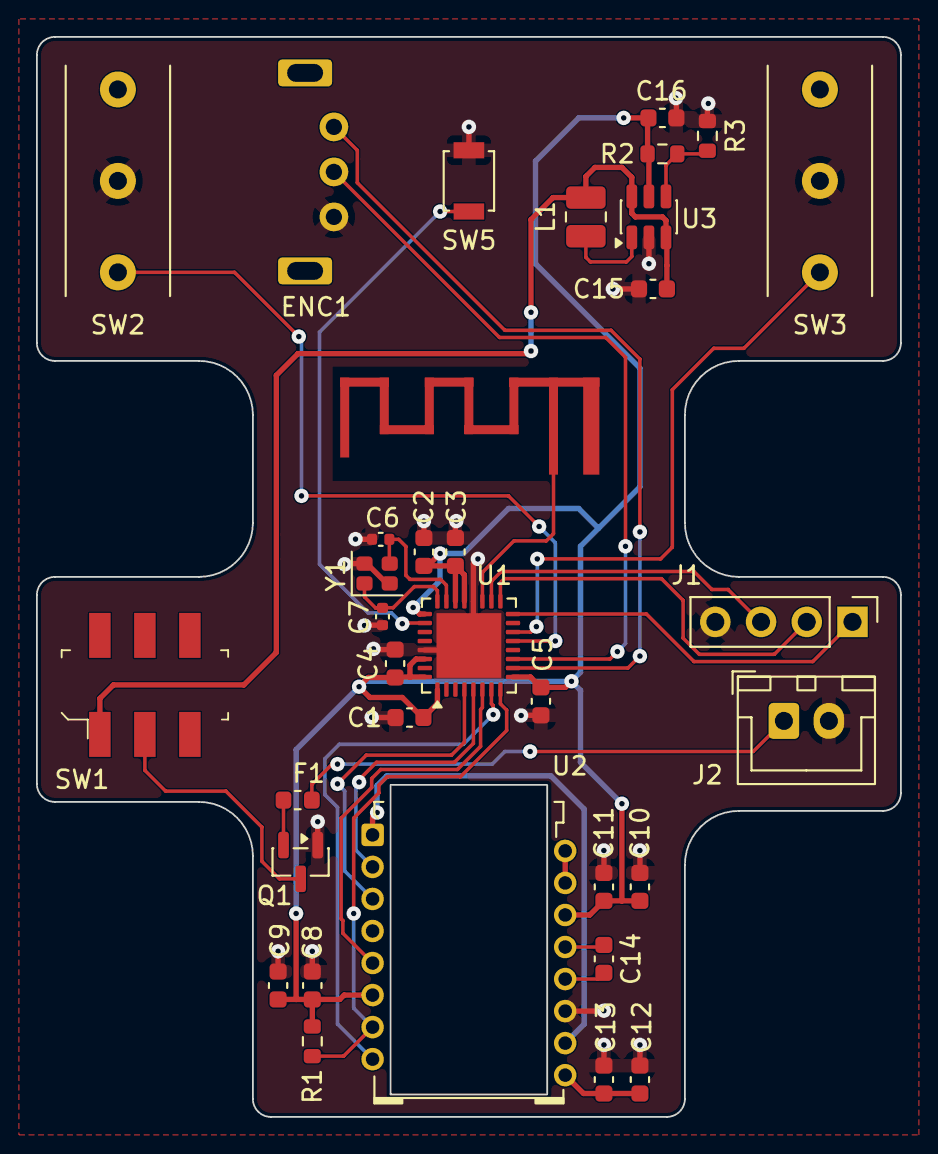
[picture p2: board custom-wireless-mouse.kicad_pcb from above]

Board: 2 copper layers, 48.0 x 60.0 mm, 33 parts (0 on the bottom side), 28 nets.

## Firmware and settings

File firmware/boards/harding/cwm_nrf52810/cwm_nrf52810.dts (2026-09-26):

/*
 * SPDX-License-Identifier: Apache-2.0
 *
 * Board definition for the custom wireless mouse PCB (U1: nRF52810, 32-QFN
 * 5x5mm package). See docs/hardware/ for the full electrical design this
 * board file targets, in particular pinout.md and open-items.md — several
 * peripheral nodes below are deliberately left unassigned pending the GPIO
 * pin assignment open item.
 */

/dts-v1/;
#include <nordic/nrf52810_qfaa.dtsi>
#include "cwm_nrf52810-pinctrl.dtsi"

/ {
	model = "Custom Wireless Mouse (nRF52810)";
	compatible = "harding,cwm-nrf52810";

	chosen {
		zephyr,sram = &sram0;
		zephyr,flash = &flash0;
	};

	/*
	 * Not yet defined here, pending pin assignment
	 * (docs/hardware/open-items.md, item 5):
	 *
	 *   - spi1: bus to U2 (PMW3610), pinctrl for SCLK/SDIO/NCS
	 *     (docs/hardware/pinout.md, U1 section)
	 *   - gpio-keys: BTN_L (SW2), BTN_R (SW3), BTN_FN (SW4), WHEEL_SW
	 *   - PMW3610 MOTION line as a GPIO interrupt input
	 *   - WHEEL_A / WHEEL_B quadrature inputs for ENC1
	 *
	 * Add these once layout fixes the P0.xx assignment for each signal.
	 */
};

/*
 * P0.21 doubles as the SWD RESET line (J1) per
 * docs/hardware/pinout.md — configure it as external reset rather than a
 * general-purpose GPIO.
 */
&uicr {
	gpio-as-nreset;
};

&gpiote {
	status = "okay";
};

&gpio0 {
	status = "okay";
};

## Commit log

2026-09-26 Add hardware/firmware scaffolding and a complete, audited schematic
    - Scaffold firmware/ (nRF Connect SDK) and hardware/ (KiCad 10 project)
    with self-contained, kebab-case-named vendored symbol/footprint
    libraries and datasheets for every non-passive part.
    - Draw the full schematic (power, MCU, sensor, I/O sections), verified
    clean with kicad-cli sch erc.
    - Re-audit the BOM independently, catching and fixing two real design
    issues: crystal load capacitance exceeded the MCU's documented
    oscillator maximum, and the charge-pump flying-cap value was
    mis-inferred in the earlier draft. Replace previously unaudited
    parts (slide switch, SWD header) with specific, stock-verified ones.
    -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
    [custom-wireless-mouse.kicad_pcb, custom-wireless-mouse.kicad_sch]
2026-09-26 Manual schematic cleanup pass (layout, routing, net naming)
    Reworked wire routing and component placement by hand for readability,
    and renamed several nets (VBAT/VBAT_SW, nRESET, etc). Known issues from
    an audit of this pass, not yet fixed:
    - J1's physical pin assignment no longer matches its own symbol's pin
    labels: pin 1 (labeled SWDIO) now carries nRESET, pin 3 (labeled GND)
    carries SWDIO, pin 4 (labeled ~RESET) carries GND. Only pin 2 (SWDCLK)
    is still correct.
    - 5 of the 6 PWR_FLAG markers were removed, so ERC now flags U2's
    charge-pump/laser-driver nets, U3's VBAT net, and the GND net as
    undriven. Wiring on all of these is still correct per the netlist;
    this is only a miss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
    [custom-wireless-mouse.kicad_sch]
2026-09-27 Add JST B2B-XH-A battery connector to schematic and libraries
    B1 (Device:Battery_Cell) is netted in the schematic but has an empty
    Footprint field, so nothing would be placed on the PCB for it - there
    was no physical way to actually plug in a battery. Added the JST XH
    2-position pin header (B2B-XH-A) as J2, vendored from KiCad's own
    official Connector_JST library (symbol, footprint, and 3D model, all
    CC-BY-SA 4.0) plus its public datasheet. Placed unwired on the
    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
    [custom-wireless-mouse.kicad_sch]
2026-09-27 Add reverse-battery and short-circuit protection parts (unwired)
    Placed Q1 (Diodes Inc DMP2035U, low-threshold P-channel MOSFET) and F1
    (Littelfuse 0603L010 PPTC resettable fuse) on the schematic near J2,
    vendored with real datasheets. Q1 is a high-side ideal-diode reverse-
    polarity protector (Source toward the battery, Drain toward the rest
    of the circuit, Gate to GND); F1 is a self-resetting fuse sized well
    above the design's peak draw but well below a battery short. Both
    parts are placed only - not wired in - per request.
    Also includes the removal of the old placeholder B1 (Device:Battery_Cell)
    and repositioning of J2, done directly in the KiCad GUI.
    [custom-wireless-mouse.kicad_sch]
2026-09-27 Fix remaining ERC errors with PWR_FLAG markers, no rewiring
    Added 7 local:PWR_FLAG instances (no existing parts moved) to satisfy
    ERC's power_pin_not_driven / pin_not_driven checks:
    - U2 (PMW3610) CP, CN, VCP, PASS_T/+VCSEL, and XYLASER/-VCSEL nets -
    all internally driven by the sensor's own charge pump, which ERC
    can't see, so each needs its own flag.
    - U3's VBAT_SW net, undriven since Q1 (a passive-type MOSFET pin) sits
    between the battery and the regulator instead of a power-type source.
    - The rotary encoder's local ground net (previously #PWR006), which
    was disconnected from the main GND driver.
    ERC now reports 0 errors. The 2 remaining warnings are not fixable
    this way: ENC1's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
    [custom-wireless-mouse.kicad_sch]
2026-09-27 Minor GUI cleanup pass on top of the new protection/PWR_FLAG additions
    [custom-wireless-mouse.kicad_sch]
2026-09-27 Correct J1 pin labels to match wiring; document current design fully
    J1's own pin names (schematic symbol, silkscreen, and docs) now read
    1=nRESET, 2=SWDCLK, 3=SWDIO, 4=GND, matching what's actually wired to
    each physical pin. This header has no external standard to conform to
    (a plain unkeyed 4-pin 0.1" connector, unlike ARM's shrouded 10-pin
    Cortex Debug connector or a Tag-Connect footprint), so the assignment
    is this project's own choice and correcting the labels in place is a
    complete fix on its own.
    Also brought bom.md, pinout.md, schematic.md, kicad-build-guide.md,
    and open-items.md up to date throughout: J2/F1/Q1 (battery input and
    protection) documented with full pin tables and BOM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
    [custom-wireless-mouse.kicad_sch]
2026-09-27 Add programming/debugging documentation for U1
    Covers J1's SWD pinout, west flash runner integration (nrfjprog/jlink,
    pyocd, openocd), the ST-Link V3SET's known non-ST-target restriction,
    and a researched, ranked cost comparison of alternative debug probes
    from a $2 ST-Link V2 clone up to a Segger J-Link EDU Mini.
    [custom-wireless-mouse.kicad_sch]
2026-09-27 Correct R1's documented status: populated, not DNI
    Cross-checked R1 (NRESET pull-up) against the proven siderakb/pmw3610-pcb
    reference schematic (fetched and traced directly, not summarized) and 19
    pages of PixArt's own datasheet. Found no basis for the previous "built-in
    internal pull-up, R1 optional" claim in either source, and the reference
    design populates the identical resistor. The schematic wiring itself was
    already correct and already matches the reference exactly - only the BOM/
    pinout documentation is corrected here.
    Also includes the two ERC exclusions (isolated_pin_label on ANT,
    lib_symbol_mismatch on ENC1) added directly in the KiCad GUI.
2026-09-27 Replace SW2-4/ENC1 with DIY-compatible switch and real scroll encoder
    Researched against real datasheets and the DIY mouse-modding market:
    Panasonic EVQ-P7B01P (SW2-4) is an SMD tactile switch in a fundamentally
    different, much smaller footprint than any common 2-pin/3-pin mouse
    micro switch (Omron D2FC, Kailh GM series, Huano, TTC all share one
    ~12.8x5.8x6.5mm through-hole body) - no swap-in flexibility was actually
    possible with it. Bourns PEC11R-4220F-S0012 (ENC1) is vertical-mount
    only with an oversized 6mm shaft - wrong orientation and wrong diameter
    for a flat-PCB mouse scroll wheel, though its built-in pushbutton did
    work.
    Replaced with:
    - SW2-4 (L/R/FN) and new SW5 (wheel middle-cli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
    [custom-wireless-mouse.kicad_sch]
2026-09-27 Clean up the new switch and encoder symbol graphics
    Both were legible but visually cluttered - pin name text (COM/NO/NC,
    A/B/COM) overlapped the switch contacts and the encoder's shaft circle.
    Rebuilt the switch on KiCad's own official SW_SPDT graphic convention
    (hidden pin names, contact dots, a diagonal blade line) and gave the
    encoder more clearance between its body and pin stubs. Both now hide
    pin names by default, matching how KiCad's own switch symbols are
    drawn, with pin numbers alone identifying each terminal.
    [custom-wireless-mouse.kicad_sch]
2026-09-27 Document User Input section as fully wired
    ENC1 and SW2-SW5 are wired: WHEEL_A/WHEEL_B to the encoder, BTN_L/
    BTN_R/BTN_FN/BTN_SCRL to their switches, all NO/COM pins to GND with
    NC left open. BTN_SCRL runs on U1 pin 26 (P0.25); pin 12 (P0.15) is a
    reserved spare alongside P0.00/P0.01/P0.28/P0.30. ERC: 0 errors, 0
    warnings.
    [custom-wireless-mouse.kicad_sch]
2026-09-27 Audit 3D model coverage for every vendored part
    Added a close-approximation 3D model for U1 (KiCad's own EP3.7x3.7mm
    QFN-32 shape substituted for the exact EP3.6x3.6mm variant, which has
    no bundled model anywhere in KiCad's 3D pack - differs only in an
    invisible interior exposed-pad dimension).
    For the four parts left without one, did a real search rather than
    assuming absence: SW1 (JS202011SCQN) and SW2-SW5 (D2FC-F-7N(20M)) both
    have confirmed, real STEP models on Ultra Librarian/SnapEDA/GrabCAD/
    TraceParts, but all four sites blocked automated download behind
    Cloudflare or account gates - direct links for a quick manual pull are
    recorded in each part's ATTRIBUTION.md. U2 (PMW3610DM-SUDU)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
2026-09-27 Add real vendor/community 3D models for the four remaining parts
    JS202011SCQN (SW1), D2FC-F-7N(20M) (SW2-5), NRF52810-QCAA-T (U1), and
    the TTC 5mm mouse encoder (ENC1) each now carry a real STEP file
    (Ultra Librarian for the first two, GrabCAD for the encoder),
    downloaded manually and placed unmodified in each part's 3dmodels/
    folder. U1's model replaces the earlier same-family approximation now
    that the exact part's own model is in hand.
    All footprint (model ...) references verified to resolve to real,
    present files. Every vendored part in the project now has a 3D model
    except U2 (PMW3610DM-SUDU), for which none exists on any channel
    checked.
2026-09-27 Add PMW3360 3D model as a verified substitute for U2
    No 3D model exists for PMW3610DM-SUDU anywhere. Sourced a community
    GrabCAD model of PixArt's PMW3360DM-T2QU instead and verified it
    dimensionally against PMW3610's own datasheet package outline drawing
    before using it - every external figure (body size, shoulder width,
    depth, pin count/pitch/width) matches exactly, and both parts share
    the same "_16A" molded lead-frame package tooling family per PixArt's
    own package document numbers. The one real difference is internal
    (VCSEL laser aperture vs. IR LED aperture), not the body/pin geometry.
    Every component in the schematic now resolves a real 3D model - 34/34,
    full coverage. ERC: 0 errors,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
2026-09-27 Full BOM sourcing audit against Canadian distributors, swap Q1 to DMG2305UXQ
    Every schematic component now carries verified Manufacturer/MPN/Distributor/
    DPN fields, checked against DigiKey.ca as of 2026-09-27. Corrected several
    components to their full orderable part numbers (Y1, F1, J2), fixed L1's
    oversized placeholder footprint to match the real Murata part, and flagged
    two live supply-chain risks (SW2-5 EOL, Q1 lead time) directly in the docs.
    Q1 swapped from DMP2035U-7 (out of stock, 40-week lead) to DMG2305UXQ-7:
    same SOT-23 pinout, in stock at DigiKey.ca, and a tighter gate threshold
    (-0.9V max vs -1.0V) that narrows rather than widens the documented
    near-dead-battery corner case. V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
    [custom-wireless-mouse.kicad_sch]
2026-09-27 Close out remaining open items ahead of layout
    - Battery pack sourcing: single AAA cell confirmed (weight-driven choice).
    Real harness path identified from in-stock DigiKey.ca parts (Keystone
    2467 holder + JST XHP-2/SXH-001T-P0.6, same connector family as J2).
    - Corrected a stale claim that the VBAT PWR_FLAG near J2 was unwired —
    re-traced it and it's genuinely connected to the fused-battery-rail
    net; ERC independently confirms zero unconnected wire endpoints.
    - SW2-5's EOL status downgraded from open risk to accepted/non-blocking,
    since the mod-market AliExpress fallback is a confirmed easy path.
    Remaining open items (ENC1 footprint, wheel/encoder mechanical design,
    USB dongle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
2026-09-27 Fix 3D model orientation for U1, SW1, SW2-5, and ENC1
    All four footprints' vendor/community STEP models were placed with
    identity (model ...) transforms that didn't match their own internal
    axis conventions, causing them to render sheared, rotated, or flipped
    relative to their pads. Diagnosed by parsing each STEP file's
    CARTESIAN_POINT bounding box and iteratively verifying fixes with
    `kicad-cli pcb render`:
    - U1 (Nordic QFN) and SW1 (C&K slide switch): both STEP files use a
    Y-up axis convention instead of KiCad's Z-up. Fixed with a -90
    rotation about X on each.
    - SW2-5 (Omron D2FC, 4 instances): STEP model's long axis and origin
    didn't match the footprint's local frame. Fixed with a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
    [custom-wireless-mouse.kicad_pcb]
2026-09-27 Sync ENC1 and PMW3610 footprints from library after 3D model tweaks
    Re-ran the footprint-library sync (identical mechanism as the earlier
    U1/SW1/SW2-5/ENC1 orientation fixes) to bring two manually-tweaked
    vendored footprints into the placed PCB instances: ENC1's refined
    encoder model transform and added mounting pads, and U2/PMW3610's
    adjusted sensor rotation. Position, orientation, custom sourcing
    fields, and net connections were all preserved during the sync;
    DRC re-confirmed clean afterward.
    [custom-wireless-mouse.kicad_pcb]
2026-09-27 Swap SW5 to a low-profile switch that clears the scroll wheel
    SW5 (wheel middle-click) previously reused the same Omron D2FC-F-7N(20M)
    as SW2-4, but that part's 6.5mm THT body doesn't fit underneath the
    scroll wheel, which mounts on ENC1's shaft directly above it.
    Deep-audited real, in-stock DigiKey.ca alternatives against the height
    constraint and selected Omron B3U-1000P: 1.6mm actuator height, 2-pin
    SPST-NO, exact-match footprint and 3D model already in KiCad's own
    official library. Vendored the real datasheet, symbol, footprint, and
    3D model; registered the new library; swapped SW5's schematic symbol,
    footprint, and sourcing fields.
    The old part's 3-pin COM/NO/NC wiring doesn't map ont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
    [custom-wireless-mouse.kicad_sch]
2026-10-04 First-pass routing, remove function button, rewire SW5
    Routed the board (ENC1/SW2/SW3/SW5/U1/U3/J1/J2/Q1/antenna feed all
    connected) and placed a meandered PCB trace antenna. DRC dropped from
    13 violations / 53 unconnected items to 1 violation / 0 unconnected.
    Removed SW4 (function/DPI button) for lack of routing space -- dropped
    its footprint, its BTN_FN net, and the now-stale references across
    docs. U1 pin 15 (P0.20) is now a spare no-connect GPIO. Any DPI/secondary
    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
    [custom-wireless-mouse.kicad_pcb, custom-wireless-mouse.kicad_sch]
2026-10-04 Check design against JLCPCB's published manufacturing capabilities
    Added docs/hardware/jlcpcb-capabilities.md comparing this board's actual
    PCB/PCBA specs (layer count, board size, track/clearance, drill sizes,
    component packages, via annular ring) against JLCPCB's current published
    PCB, PCBA, and stencil capability limits.
    Everything checks out except the vias: all 50 are 0.6mm pad / 0.3mm
    drill (0.15mm annular ring), below JLCPCB's stated 0.18mm absolute
    minimum for a 2-layer board. Tried widening them to 0.7mm and 0.8mm and
    re-running DRC both times -- each introduced dozens of new clearance
    violations since routing was done tight around the original via size, so
    reverted rather than for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
2026-10-04 Resize vias to meet JLCPCB's annular ring minimum
    All 50 vias were reworked and resized to 0.8mm pad / 0.3mm drill
    (0.25mm annular ring), meeting JLCPCB's recommended value rather than
    just their 0.18mm absolute minimum for a 2-layer board. DRC confirms no
    new violations (still only the pre-existing antenna-keepout error, 0
    unconnected items).
    Updated the project's net-class via defaults and min_via_annular_width
    DRC rule to match, so future vias added via the GUI default to a
    JLCPCB-compliant size. Docs updated to mark this resolved.
    [custom-wireless-mouse.kicad_pcb]
2026-10-04 Allow tracks through the antenna keepout zone
    The "Antenna" rule area disallowed tracks alongside vias/pads/copper
    pour/footprints, which blocked the antenna's own feed trace from
    reaching the meander. Changed tracks to allowed while keeping the rest
    not_allowed, so ground pour is still excluded from the antenna area.
    kicad-cli pcb drc now reports 0 violations, 0 unconnected items.
    [custom-wireless-mouse.kicad_pcb]
